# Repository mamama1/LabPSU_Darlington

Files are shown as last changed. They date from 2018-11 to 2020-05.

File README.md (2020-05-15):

# LabPSU_Darlington

Welcome to my Lab PSU project, which is based on a pair of BD139/TIP3055 Darlingtons and the Teensy 3.5 (3.6 should work as well).<br><br>

This project has been heavily inspired by the original µSupply project by Dave Jones from the EEVBlog.<br>
Link: https://www.eevblog.com/projects/usupply/ <br><br>

Specs:<br>
0 - 16.384V output controllable in 1mV steps<br>
0 - 4096 mA output controllable in 1mA steps<br>
Around 0.1% accuracy due to high accuracy components<br>
16 Bit DACs (DAC8311)<br>
High precision voltage reference for the DACs (REF5040)
16 Bit ADCs (ADS1115)<br>
Low Ripple, Low Noise<br>
25kHz PWM/temperature controlled Fan output for standard PWM capable FANs<br>
One Board solution (toroidal transformer not onboard)<br>
Optional Front Panel for Display, rotary encoder, button and LED mounting<br>
Fast UI thanks to Teensy's 120 MHz frequency<br>
Header for ESP8266, ESP32 or basically any other UART compatible device, including 3.3V and GND as well as two I/O pins (one PWM capable)

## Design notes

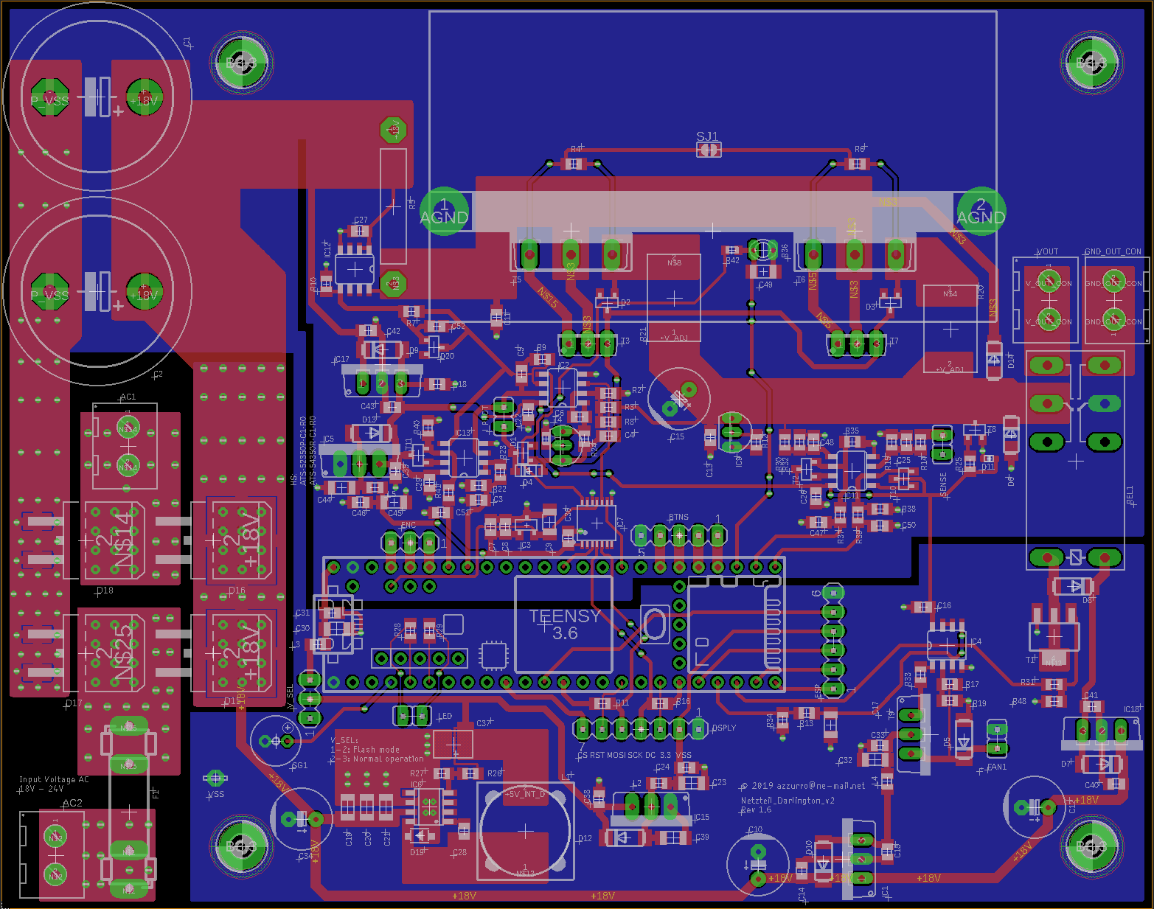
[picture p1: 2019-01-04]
Hardware/preview.PNG

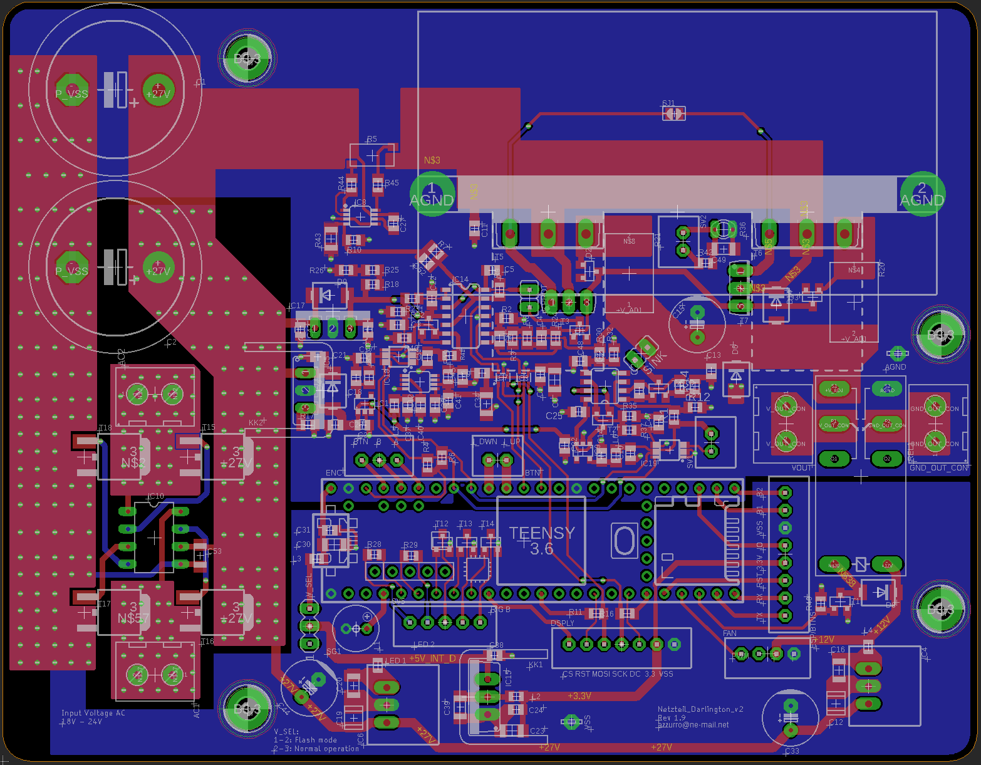
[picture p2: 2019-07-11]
preview.PNG

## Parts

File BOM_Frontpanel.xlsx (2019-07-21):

Qty | Value | Device | Package | Parts | Description | OC_MOUSER
1 |  | EC12E-SW | EC12E-SW | SW1 | ALPS ENCODER EC12-E with switch | 652-PEC11R-4225F-S24
1 |  | JST-PH-2.0-2P | JST-PH-2.0-2P | LED | PIN HEADER | 455-1704-ND
2 |  | JST-PH-2.0-3P | JST-PH-2.0-3P | ENC, RGB-LED | PIN HEADER | 455-1705-ND
1 |  | JST-PH-2.0-5P | JST-PH-2.0-5P | BTN | PIN HEADER | 455-1707-ND
1 |  | JST-PH-2.0-7P | JST-PH-2.0-7P | DSPLY | PIN HEADER | 455-1709-ND
1 |  | LED-RGB | C1411 | LED4 | LED | 710-150141M173100
4 |  | TS1B3F-10XX | B3F-10XX | TS1, TS2, TS3, TS4 |  | 653-B3F-1022
2 | 10k | R-SMD0805 | C0805K | R2, R3 | R | 652-CR0805-JW-103ELF
1 | 68R 1% 1/10W | R-SMD0805 | C0805K | R4 | R | 652-CR0805FX-68R0ELF
2 | 6R 1% 1/10W | R-SMD0805 | C0805K | R1, R5 | R | 652-CR0805-J/-6R2ELF
1 | DOC-R1.27 | DOC-R1.27 | DRAWINGNAME-1.27 | DNX-NAME-1 | devnetX Document Right
1 | G | LED0805 | LED0805 | LED1 | LED | 710-150080GS75000
6 | MOUNT-PAD-ROUND3.3 | MOUNT-PAD-ROUND3.3 | 3,3-PAD | H1, H2, H3, H4, H5, H6 | MOUNTING PAD, round
1 | NHD-2.7-12864WDW3 | NHD-2.7-12864WDW3 | NHD-2.7-12864WDW3 | DSPLY1 |  | 763-NHD2712864WDW3
1 | Y | LED0805 | LED0805 | LED2 | LED | 710-150080YS75000

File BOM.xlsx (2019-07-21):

Qty | Value | Device | Package | Parts | Description | OC_MOUSER | OC_MOUSER_ADD | OC_MOUSER_ADD2
2 |  | JP1E | JP1 | I_PROT, SINK | JUMPER
3 |  | JST-PH-2.0-2P | JST-PH-2.0-2P | BTN, NTC, NTC_ADC | PIN HEADER
1 |  | JST-PH-2.0-3P | JST-PH-2.0-3P | ENC | PIN HEADER
1 |  | JST-PH-2.0-4P | JST-PH-2.0-4P | FAN | PIN HEADER
1 |  | JST-PH-2.0-5P | JST-PH-2.0-5P | LED | PIN HEADER
1 |  | JST-PH-2.0-7P | JST-PH-2.0-7P | DSPLY | PIN HEADER
1 |  | JST-PH-2.0-8P | JST-PH-2.0-8P | ESP/BTNS | PIN HEADER
1 |  | KL2691311500002 | KL2-691311500002 | VOUT | Printklemme 2-polig | 710-691311500002 | 565-72912-2 | 565-6883
1 |  | MA03-1 | MA03-1 | V_SEL | PIN HEADER
2 | 0R1 0.5% 7W | R-SMDSLN2 | SLN2 | R20, R21 | R | 66-SLN5TTED82L0D
1 | 1.27R 1% 1/10W | R-SMD0805 | C0805K | R19 | R | 71-CRCW08051R27FKEA
2 | 10.1k 0.1% 10ppm 1/10W | R-SMD0805 | C0805K | R22, R32 | R | 660-RN732ATTD1012B25
2 | 10000µ/50V | CPOL-USE10-22.5 | EB22,5D | C1, C2 | POLARIZED CAPACITOR, American symbol | 647-UVZ1H103MRD
2 | 100R 0.1% 5ppm 1/10W | R-SMD0805 | C0805K | R44, R45 | R | 756-PCF080513100RBT1
1 | 100k | NTC640 | P640 | R36 | PHILIPS NTC | 594-NTCLE213E3104HXB
1 | 100n opt/50V | CC/0805 | 805 | C13 | Kondensator | 810-C2012X7R2A104K
9 | 100n/16V | CC/0805 | 805 | C3, C7, C9, C10, C17, C24, C31, C38, C48 | Kondensator | 810-C2012X7R2A104K
5 | 100n/35V | CC/0805 | 805 | C22, C25, C28, C40, C43 | Kondensator | 810-C2012X7R2A104K
1 | 100n/50V | CC/0805 | 805 | C27 | Kondensator | 810-C2012X7R2A104K
3 | 100µ/50V | C+3.5/8 | C+/3.5/8 | C15, C33, C44 |  | 667-EEU-FR1H101
1 | 10R 0.5% 50 ppm 1/4W | R-SMD0805 | C0805K | R14 | R | 660-SG73G2ATTD10R0D
1 | 10k 0.1% 10ppm | R-SMD0805 | C0805K | R2 | R | 667-ERA-6ARW103V
4 | 10k 5% 1/10W | R-SMD0805 | C0805K | R4, R6, R7, R48 | R | 652-CR0805-JW-103ELF
1 | 10m 0.1% 15ppm 0.5W | R-CSM2512 | CSM2512 | R5 |  | 71-CSM25120R0100BST
2 | 10n/16V | CC/0805 | 805 | C47, C51 | Kondensator | 80-C0805C103K1R
1 | 10n/50V | CC/0805 | 805 | C4 | Kondensator | 80-C0805C103K1R
7 | 10µ/16V | CC/1206 | 1206 | C8, C20, C23, C30, C34, C39, C49 | Kondensator | 963-TMK316AB7106KL-T
1 | 10µ/25V | CC/1206 | 1206 | C16 | Kondensator | 963-TMK316AB7106KL-T
2 | 10µ/50V | CAPACITOR-1210 | C1210 | C12, C19 | Capacitors | 81-GRM32ER71H106MA2L
1 | 12k 0.5% 50 ppm 1/10W | R-SMD0805 | C0805K | R1 | R | 754-RR1220P-123D
1 | 1k 0.5% 50 ppm 1/10W | R-SMD0805 | C0805K | R13 | R | 754-RR1220P-102D
4 | 1k 1% 1/8W | R-SMD0805 | C0805K | R18, R24, R25, R26 | R | 652-CR0805FX-1001ELF
1 | 1k5 5% 1/8W | R-SMD0805 | C0805K | R15 | R | 652-CR0805FX-1501ELF
2 | 1n/50V | CC/0805 | 805 | C5, C26 | Kondensator | 603-CC805KRX7R0BB102
5 | 1µ/16V | CC/0805 | 805 | C14, C18, C36, C41, C45 | Kondensator | 963-UMK212B7105KG-T
3 | 1µ/35V | CC/0805 | 805 | C32, C35, C37 | Kondensator | 963-UMK212B7105KG-T
1 | 1µ/50V | CC/1206 | 1206 | C53 | Kondensator | 603-CC126KKX7R9BB105
2 | 2.2k 5% 1/10W | R-SMD0805 | C0805K | R37, R41 | R | 652-CR0805FX-2201ELF
2 | 220R 5% 1/10W | R-SMD0805 | C0805K | R28, R29 | R | 652-CR0805FX-2200ELF
1 | 221R 0.5% 50ppm 1/10W | R-SMD0805 | C0805K | R12 | R | 754-RR1220P-2210D-M
2 | 22R 5% 1/10W | R-SMD0805 | C0805K | R11, R16 | R | 652-CR0805JW-220ELF
1 | 22p opt/35V C0G | CC/0805 | 805 | C52 | Kondensator | 603-CC805JRNPO9BN220
1 | 22pF/35V C0G | CC/0805 | 805 | C6 | Kondensator | 603-CC805JRNPO9BN220
1 | 2k2 5% 1/8W | R-SMD0805 | C0805K | R17 | R | 652-CR0805JW-222ELF
1 | 30k 0.1% 10ppm | R-SMD0805 | C0805K | R3 | R | 667-ERA-6ARW303V
1 | 330n opt/50V | CC/0805 | 805 | C11 | Kondensator | 80-C0805C334K5RECTU
2 | 330n/50V | CC/0805 | 805 | C21, C42 | Kondensator | 80-C0805C334K5RECTU
1 | 4.7k 1% 1/10W | R-SMD0805 | C0805K | R9 | R | 652-CR0805FX-4701ELF
2 | 4.7k 5% 1/10W | R-SMD0805 | C0805K | R35, R40 | R | 652-CR0805FX-4701ELF
1 | 4.7k opt 1% 1/10W | R-SMD0805 | C0805K | R10 | R | 652-CR0805FX-4701ELF
1 | 47k 1% 1/10W | R-SMD0805 | C0805K | R8 | R | 652-CR0805FX-4702ELF
1 | 5k 0.1% 25ppm | R-EU_R1206 | R1206 | R43 | RESISTOR, European symbol | 71-TNPW12065K00BEEN
1 | 64.9k 1% 1/10W | R-SMD0805 | C0805K | R42 | R | 652-CR0805FX-6492ELF
1 | 7815TV | 7815TV | TO220V | IC5 | Positive VOLTAGE REGULATOR | 511-L7815CV-DG
1 | 7818TV | 7818TV | TO220V | IC17 | Positive VOLTAGE REGULATOR | 511-L7818CV-DG
2 | 90.9k 0.1% 10ppm 1/10W | R-SMD0805 | C0805K | R23, R30 | R | 279-RN73CA-90.9K
1 | AC1 | KL2691311500002 | KL2-691311500002 | AC1 | Printklemme 2-polig | 710-691311500002 | 693-8601.2001.08 | 693-3101.0010
1 | AC2 | KL2691311500002 | KL2-691311500002 | AC2 | Printklemme 2-polig | 710-691311500002 | 693-8601.2001.08
2 | ADS1115 | ADS1015 | MSOP10 | IC18, IC19 | ADS1015 12-BIT ADC | 595-ADS1115IDGSR
3 | BAT54FILMY | DBAT54FILMY | SOT23 | D1, D2, D3 |  | 511-BAT54FILMY
2 | BC847ALT1G | T-NPNSOT23-BEC | SOT23-BEC | T2, T11 | NPN Transistor | 863-BC847ALT1G
2 | BD139 | T-NPNTO126-ECB | TO126 | T3, T7 | NPN Transistor | 511-BD139-10
1 | BUZZER | BUZZER | 254-EMB73-RO | SG1 | BUZZER Source: Buerklin | 254-EMB73-RO
5 | CGRB307-G | DWIDE | DO214AA-CGRB307-G | D4, D6, D8, D9, D14 |  | 750-CGRB307-G
1 | D01S | D01S | D01S | KK1 | HEATSINK
2 | DAC8311 | DAC8X11 | SC-70-6 | IC3, IC7 |  | 595-DAC8311IDCKR
1 | G2R-2-DC12 | REL-2UG2R2 | REL-G2R2 | REL1 |  | 653-G2R-2-DC12
1 | GND | KL2691311500002 | KL2-691311500002 | GND_OUT_CON | Printklemme 2-polig | 710-691311500002
1 | HSOMNI-UNI-41-75 | HSOMNI-UNI-41-75 | OMNI-UNI-41-75 | HS2 |  | 567-OMNI-UNI-41-75 | 567-OMNI-UC | 567-CD-02-05-247
4 | IRFR7546TRPBF | T-NMOSNTD4963N | DPACK | T15, T16, T17, T18 | Transistor N-Channel MOSFET | 942-IRFR7546TRPBF
1 | LD33V | LD33V | TO220V | IC15 |  | 511-LD1117V33
2 | LSP13 | LSP13 | LSP13 | AGND, VSS | SOLDER PAD drill 1.3 mm, distributor Buerklin, 12H562
1 | LT4320DIL08 | LT4320DIL08 | DIL08 | IC10 |  | 584-LT4320HN8-1#PBF
1 | LTC6102HMS8#PBF | LTC6102 | MSOP8-0.65-3X3MM | IC8 |  | 584-LTC6102HMS8#PBF
4 | MOUNT-PAD-ROUND3.3 | MOUNT-PAD-ROUND3.3 | 3,3-PAD | H1, H2, H3, H4 | MOUNTING PAD, round
7 | MPZ2012S601AT000 | L0805 | C0805K | L1, L2, L3, L4, L5, L6, L8 | High Power Density, High Efficiency, Shielded Inductors | 810-MPZ2012S601AT000
2 | NCP718BSN330T1G | NCP718 | SOT23-5 | IC1, IC9 |  | 863-NCP718BSN330T1G
1 | OPA2197 | DUAL-OPVSOP8 | SOP8 | IC2 |  | 595-OPA2197IDR
5 | PMV130ENEAR | T-NMOSIRLML2502PBF | SOT23 | T1, T4, T12, T13, T14 | Transistor N-Channel MOSFET | 771-PMV130ENEAR
1 | QUAD-OPVOPA4197 | QUAD-OPVOPA4197 | SO14 | IC14 |  | 595-OPA4197IDR
1 | REF5040 | REF50XXVSSOP8 | MSOP8-0.65-3X3MM | IC12 |  | 595-REF5040AIDGKR
1 | TEENSY_3.5/3.6 | TEENSY_3.5/3.6 | TEENSY_3.5/3.6 | U$33 |  | 474-DEV-14055
2 | TIP3055 | T-NPNTOP3AV-BCE | TOP3AV | T5, T6 | NPN Transistor | 863-TIP3055G
1 | VXO78012-1000 | 78XX-DC-DC-UNI-VXO-OKI | 78XX-DC-DC | IC4 |  | 490-VXO7812-1000
1 | VXO7805-1000 | 78XX-DC-DC-UNI-VXO-OKI | 78XX-DC-DC | IC6 |  | 490-VXO7805-1000

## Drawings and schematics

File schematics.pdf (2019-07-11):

# REF3120AIDBZR or REF5020AIDR as VREF Y08500R01000F9R shunt

# AGND¹⁰⁰R ⁰.1% ⁵ppm ¹/10W

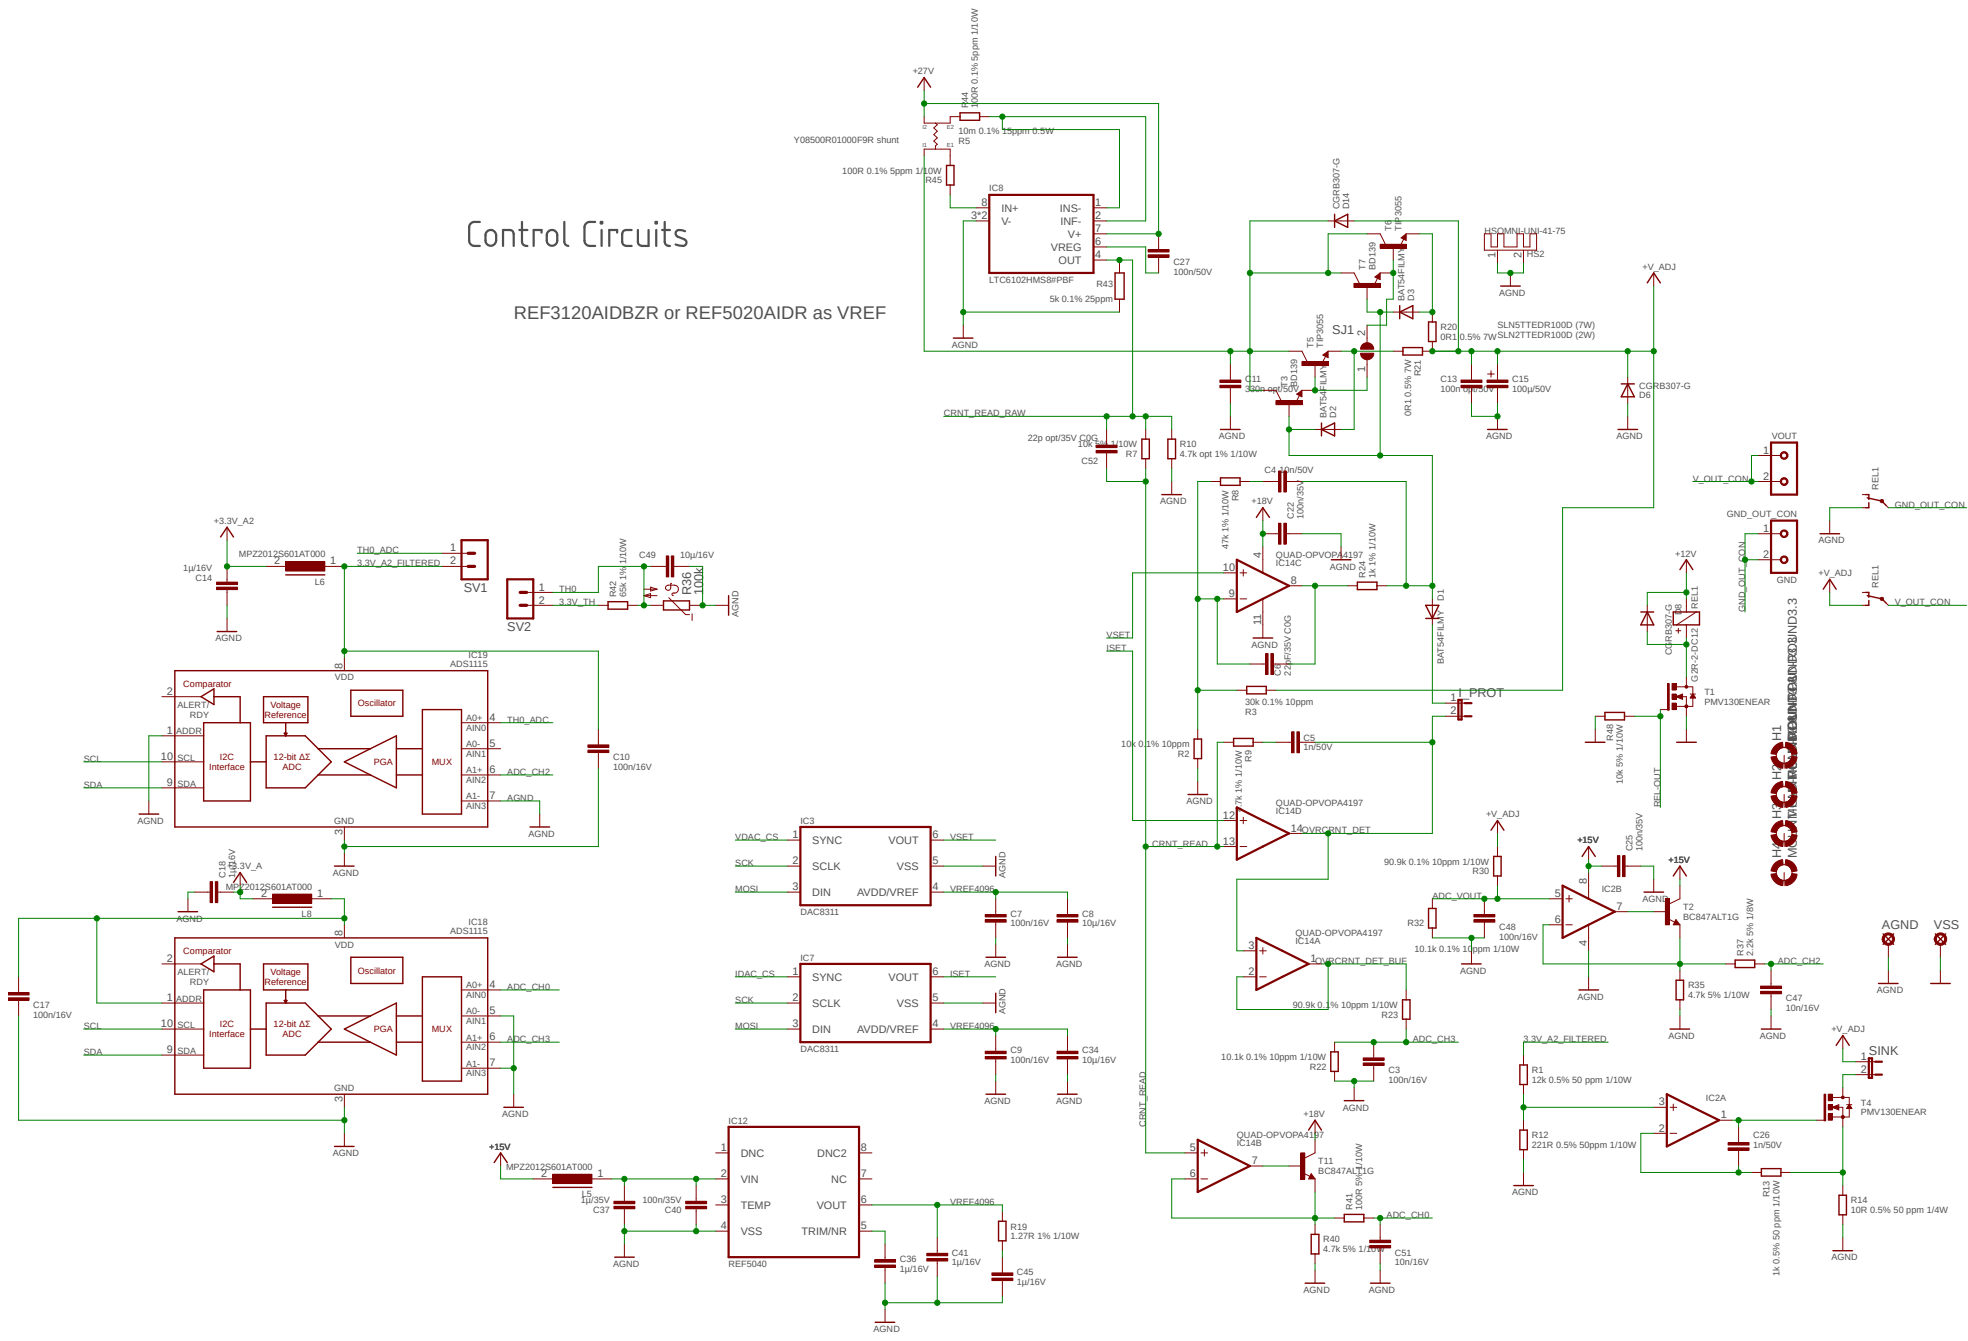
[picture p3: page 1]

## 6mA Pulldown AC¹

LT4320DIL08 IRFR⁷⁵⁴⁶TRPBF | IRFR⁷⁵⁴⁶TRPBF IRFR⁷⁵⁴⁶TRPBF | IRFR⁷⁵⁴⁶TRPBF

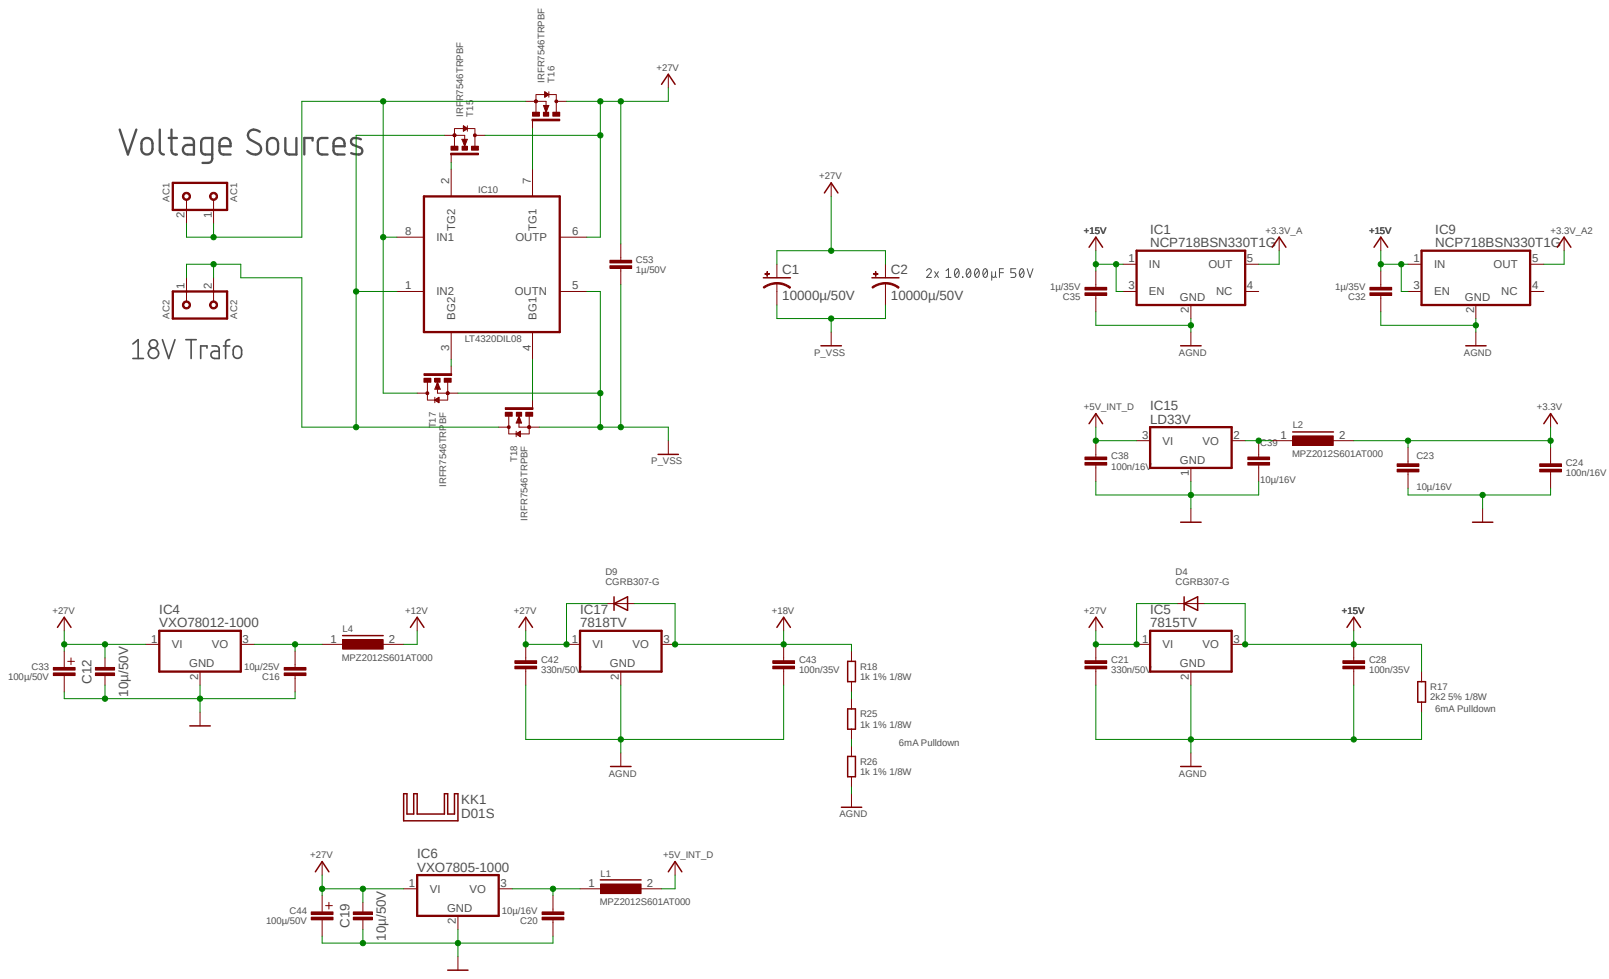
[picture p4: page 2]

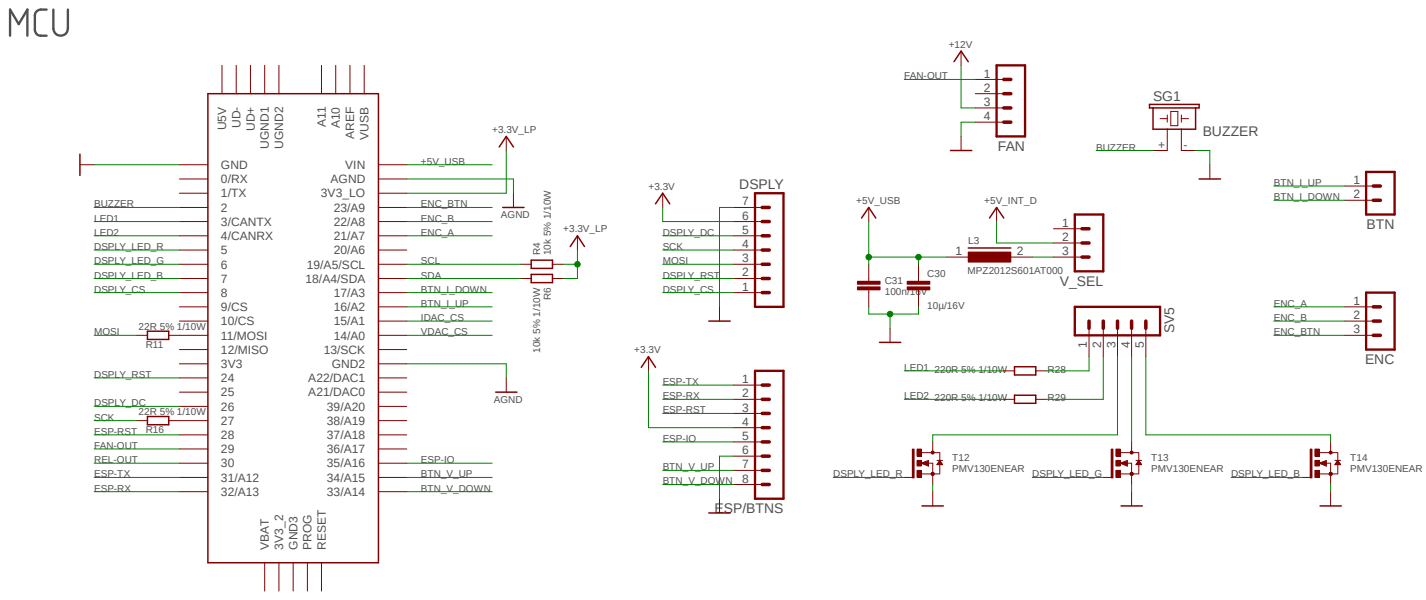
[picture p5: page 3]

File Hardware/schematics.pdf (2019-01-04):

REF3120AIDBZR or REF5020AIDR as VREF | R

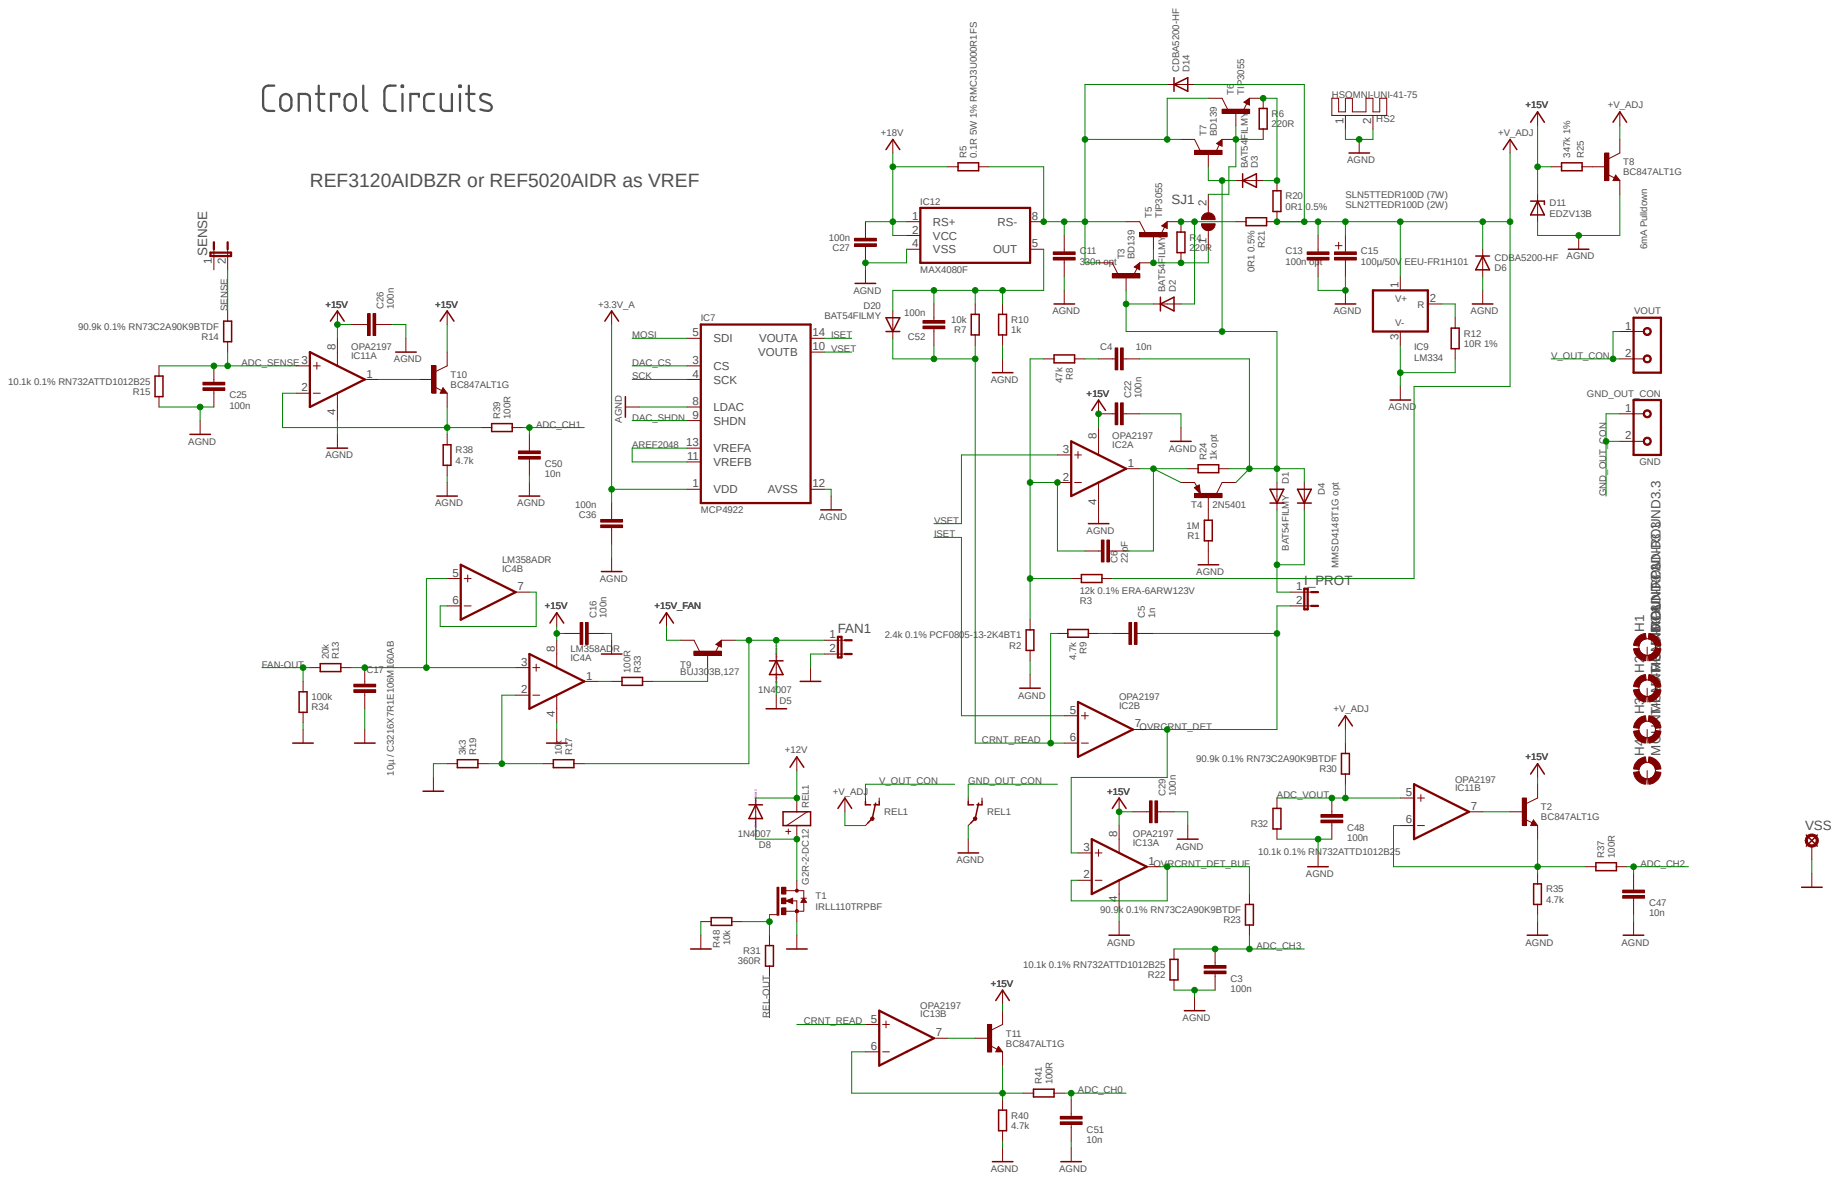
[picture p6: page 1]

SpiceOrder 1 SpiceOrder 2 SpiceOrder 1 SpiceOrder 2 6mA PulldownSLN5TTEDR100D (7W)

### 6mA Pulldown AC¹

# UVZ1H103MRD UVZ1H103MRD

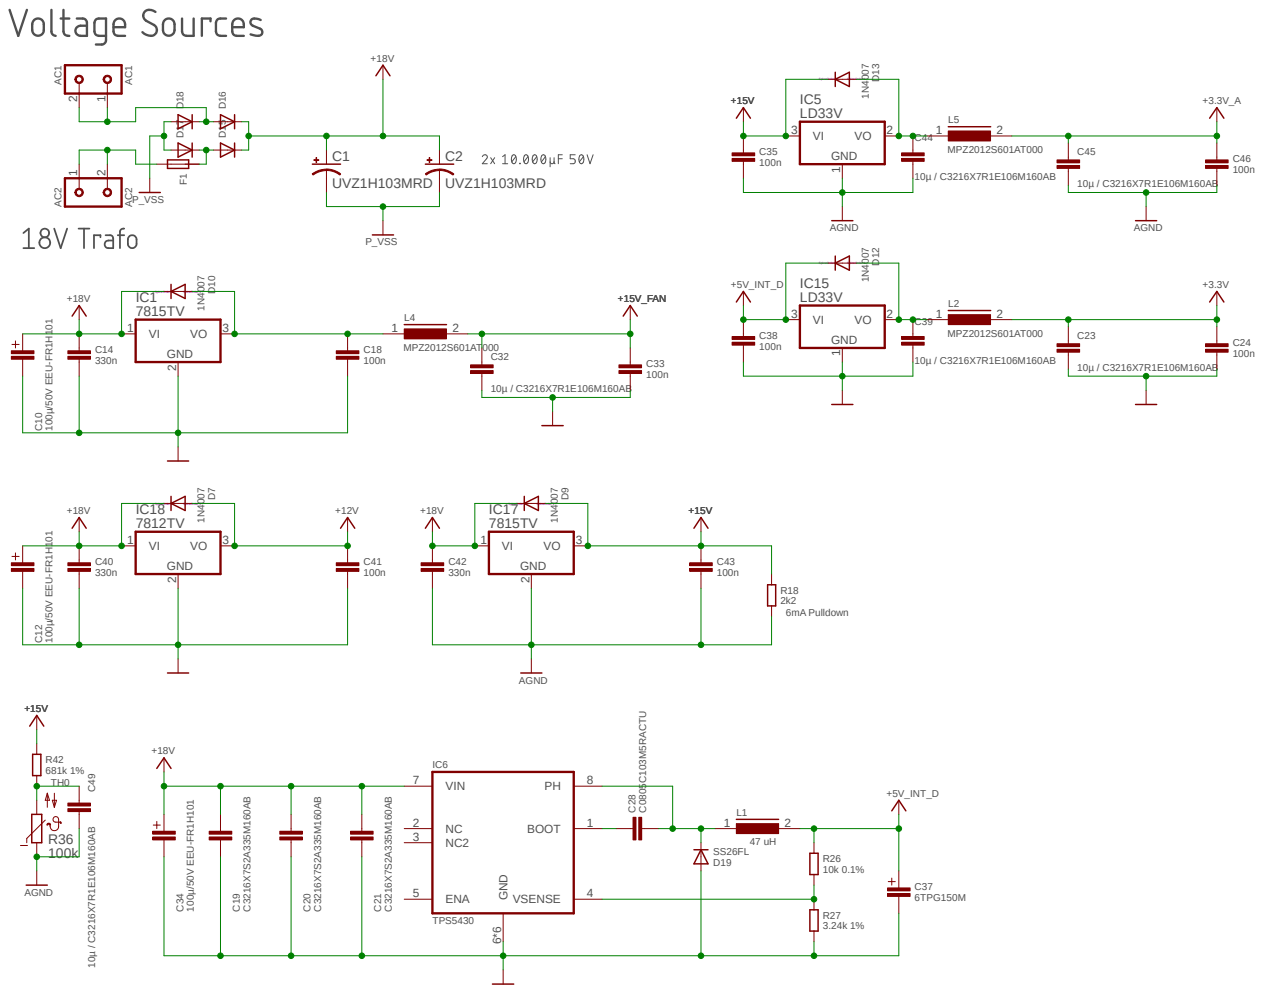
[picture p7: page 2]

P_VSS 100µ/50V EEU⁻FR¹H¹⁰¹ 100µ/50V EEU⁻FR¹H¹⁰¹

### IN OUT

### +3.3V_A

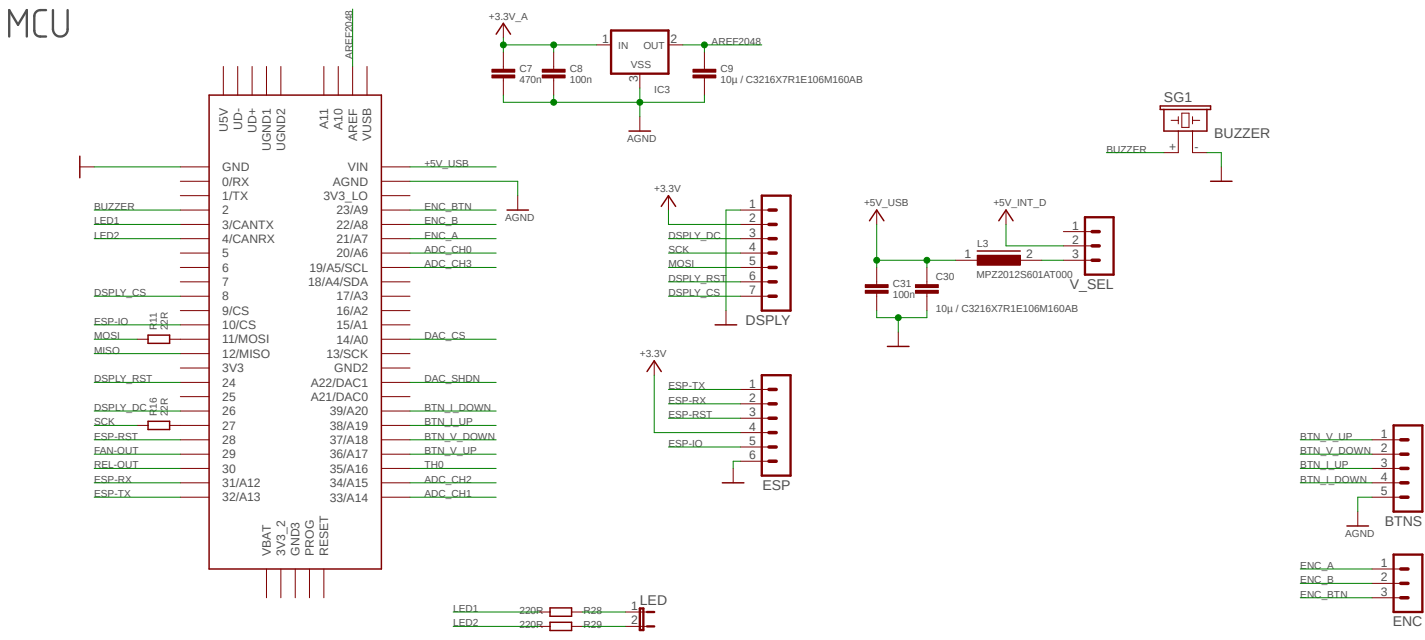
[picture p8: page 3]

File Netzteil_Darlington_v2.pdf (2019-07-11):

+

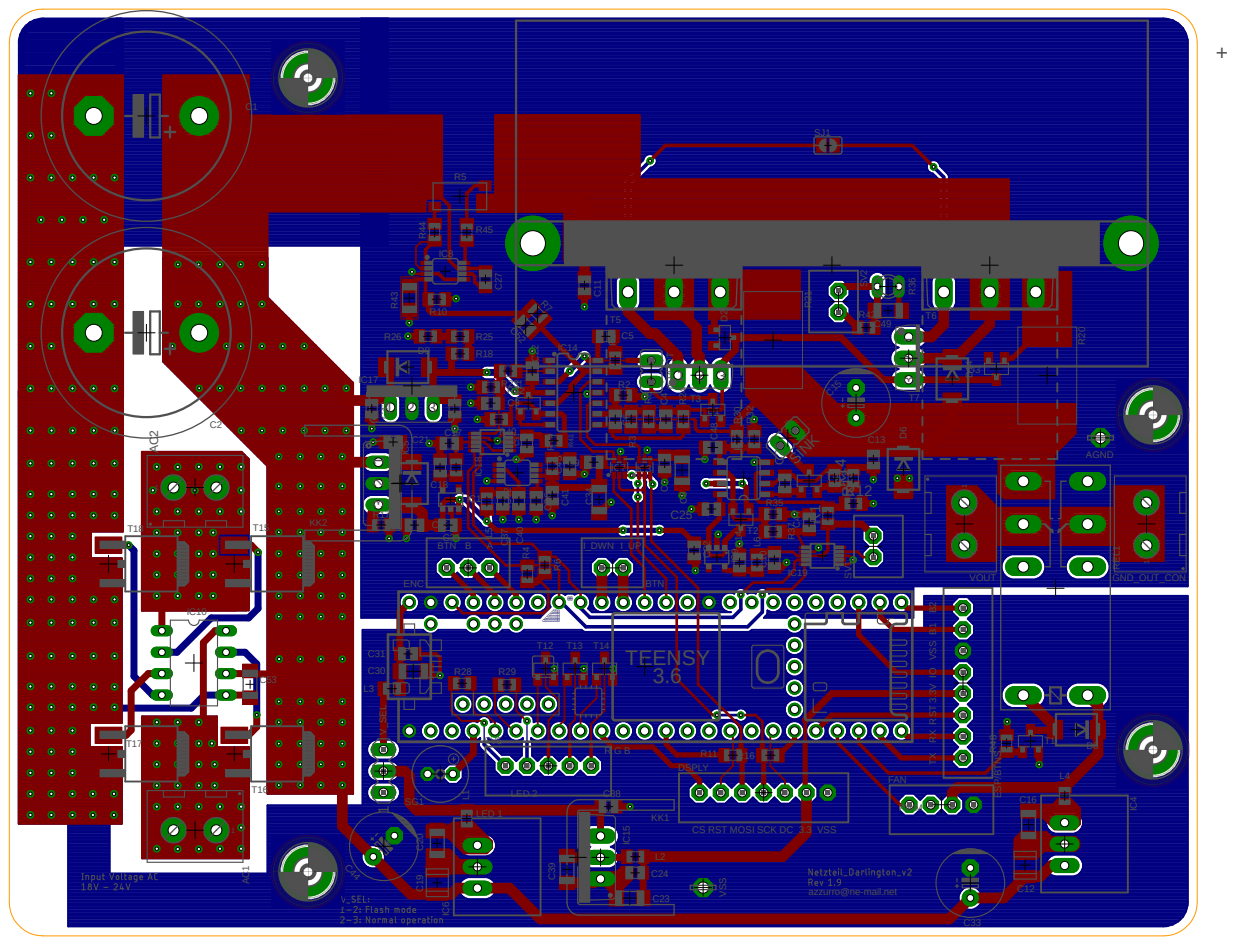
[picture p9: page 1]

+ CS RST MOSI SCK DC 3.3 VSS

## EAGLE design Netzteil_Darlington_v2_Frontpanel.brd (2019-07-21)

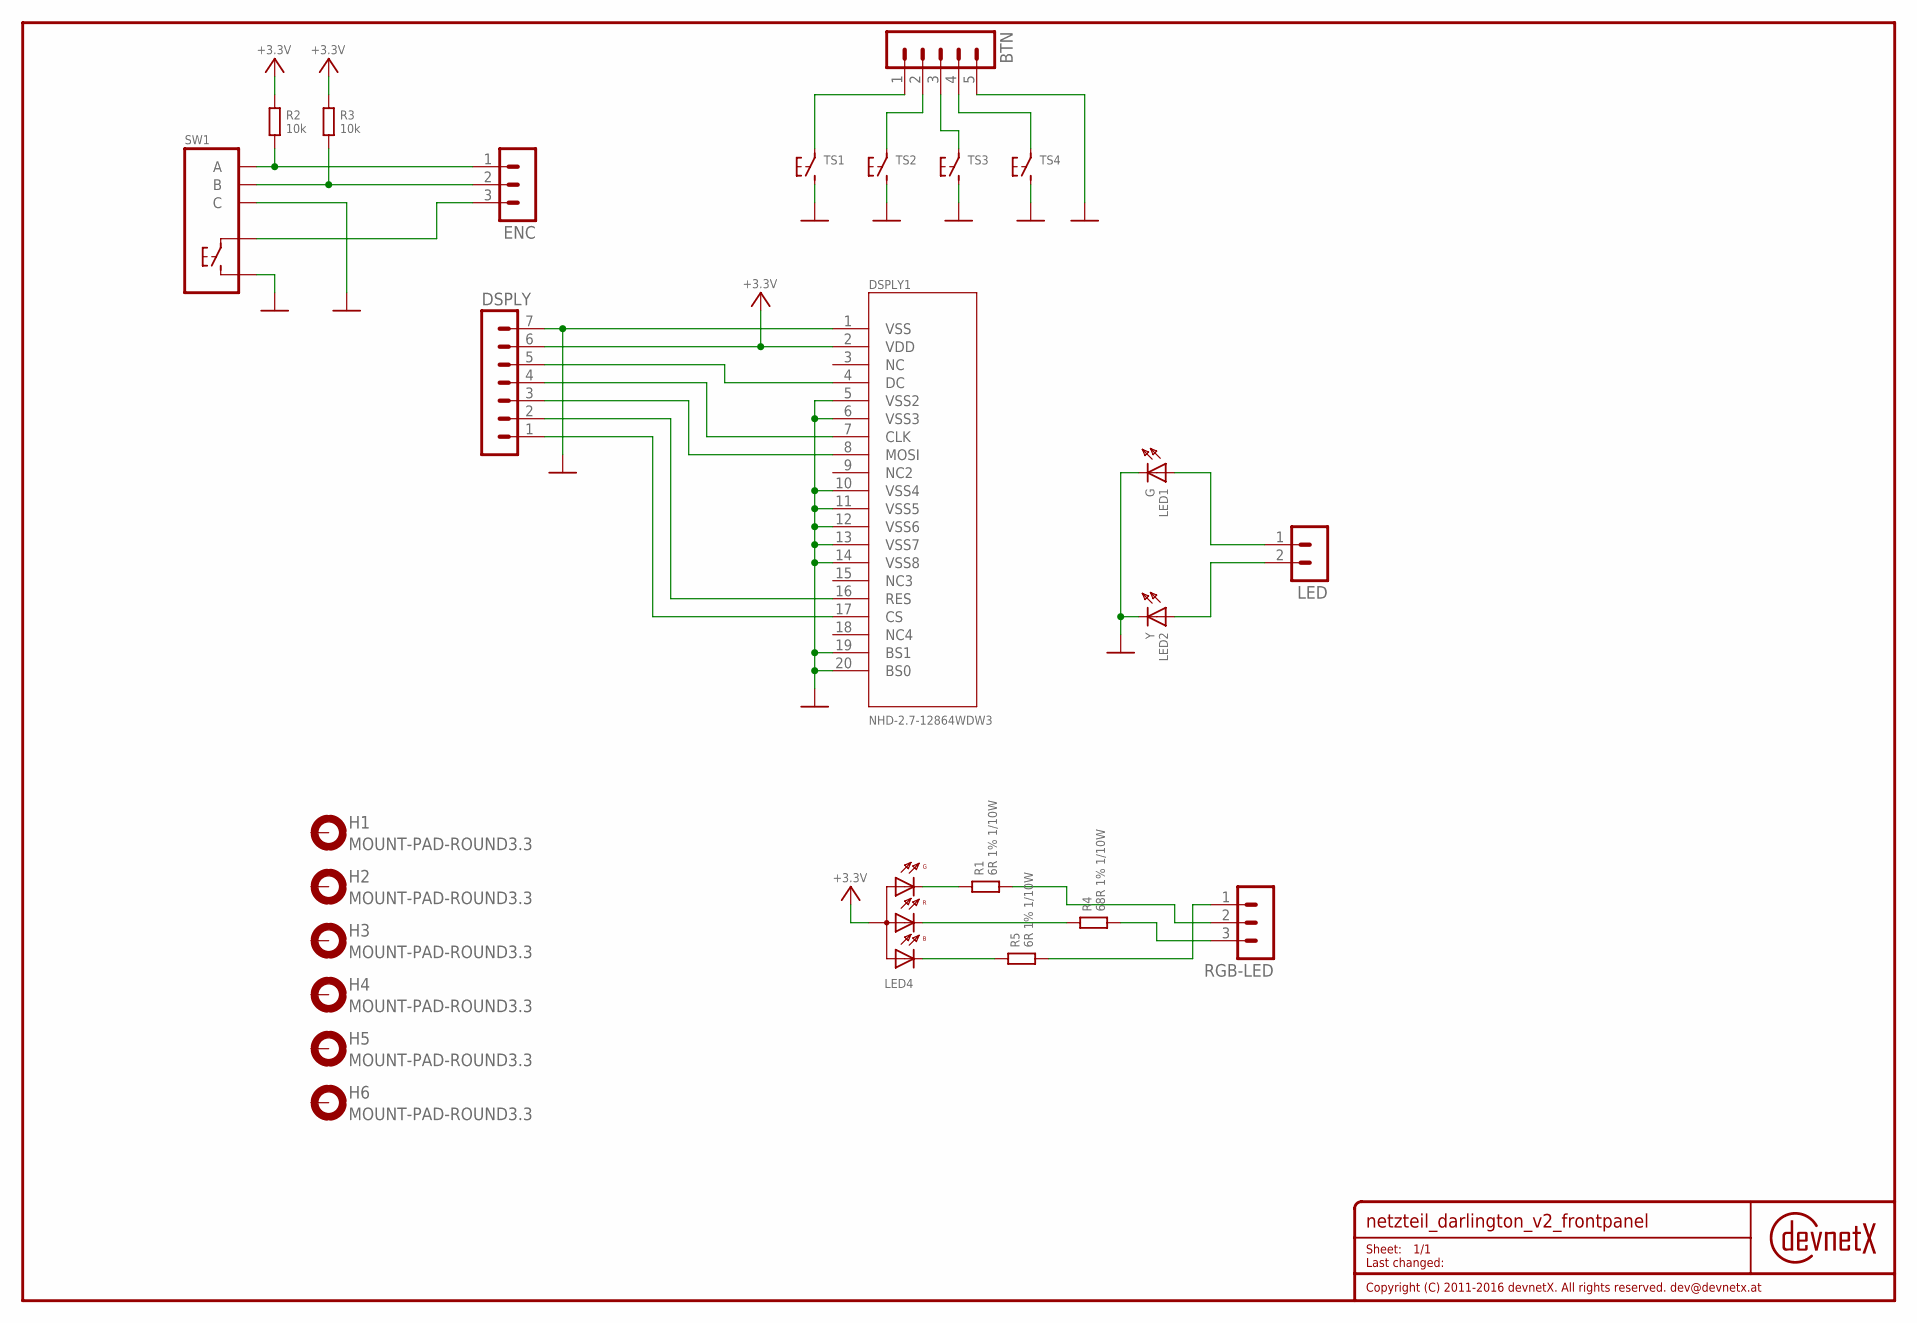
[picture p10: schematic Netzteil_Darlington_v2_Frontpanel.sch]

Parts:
BTN: JST-PH-2.0-5P
DNX-NAME-1: DOC-R1.27; DRAWINGNAME-1.27
DSPLY: JST-PH-2.0-7P
DSPLY1: NHD-2.7-12864WDW3
ENC: JST-PH-2.0-3P
H1, H2, H3, H4, H5, H6: MOUNT-PAD-ROUND3.3; 3,3-PAD
LED: JST-PH-2.0-2P
LED1: G; LED0805
LED2: Y; LED0805
LED4: LED-RGB; C1411
R1, R5: 6R 1% 1/10W; C0805K
R2, R3: 10k; C0805K
R4: 68R 1% 1/10W; C0805K
RGB-LED: JST-PH-2.0-3P
SW1: EC12E-SW
TS1, TS2, TS3, TS4: TS1B3F-10XX; B3F-10XX

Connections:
+3.3V: DSPLY.6, DSPLY1.2 (VDD), LED4.1 (A), R2.1, R3.1
unnamed: LED.1, LED1.A
unnamed: LED.2, LED2.A
unnamed: DSPLY.5, DSPLY1.4 (DC)
unnamed: BTN.1, TS1.1
unnamed: ENC.1, R2.2, SW1.A
unnamed: DSPLY.4, DSPLY1.7 (CLK)
unnamed: DSPLY.3, DSPLY1.8 (MOSI)
unnamed: LED4.4 (C4), R1.1
unnamed: ENC.2, R3.2, SW1.B
unnamed: ENC.3, SW1.1
unnamed: BTN.2, TS2.1
unnamed: BTN.3, TS3.1
unnamed: BTN.4, TS4.1
unnamed: LED4.3 (C3), R4.1
unnamed: DSPLY.2, DSPLY1.16 (RES)
unnamed: DSPLY.1, DSPLY1.17 (CS)
unnamed: LED4.2 (C2), R5.1
unnamed: R5.2, RGB-LED.1
unnamed: R4.2, RGB-LED.3
unnamed: R1.2, RGB-LED.2
VSS: BTN.5, DSPLY.7, DSPLY1.1 (VSS), DSPLY1.5 (VSS2), DSPLY1.6 (VSS3), DSPLY1.10 (VSS4), DSPLY1.11 (VSS5), DSPLY1.12 (VSS6), DSPLY1.13 (VSS7), DSPLY1.14 (VSS8), DSPLY1.19 (BS1), DSPLY1.20 (BS0), LED1.C, LED2.C, SW1.2, SW1.C, TS1.3 (2), TS2.3 (2), TS3.3 (2), TS4.3 (2)

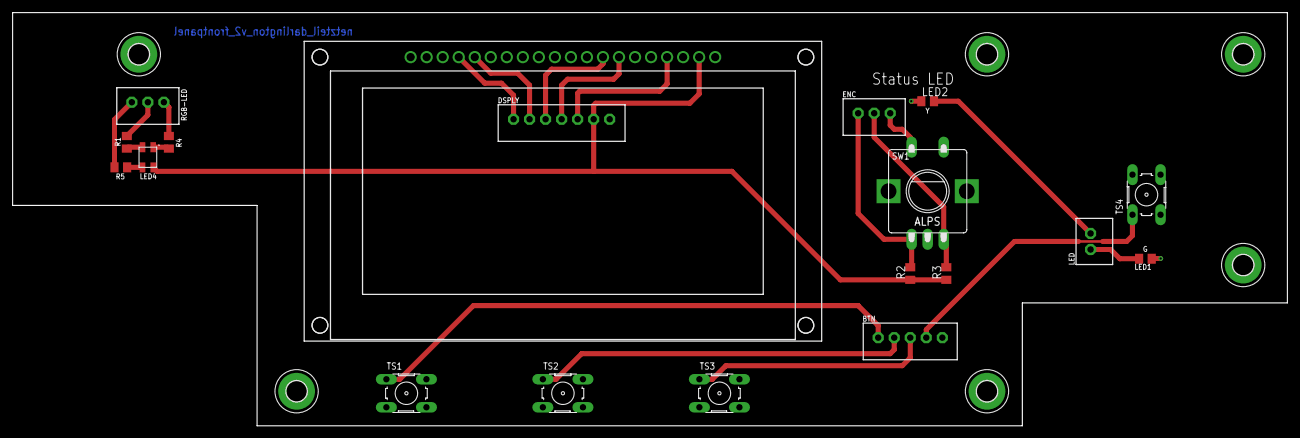
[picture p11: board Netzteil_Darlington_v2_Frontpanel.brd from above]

Board: 2 copper layers, 202.0 x 65.5 mm, 26 parts (0 on the bottom side), 22 nets.

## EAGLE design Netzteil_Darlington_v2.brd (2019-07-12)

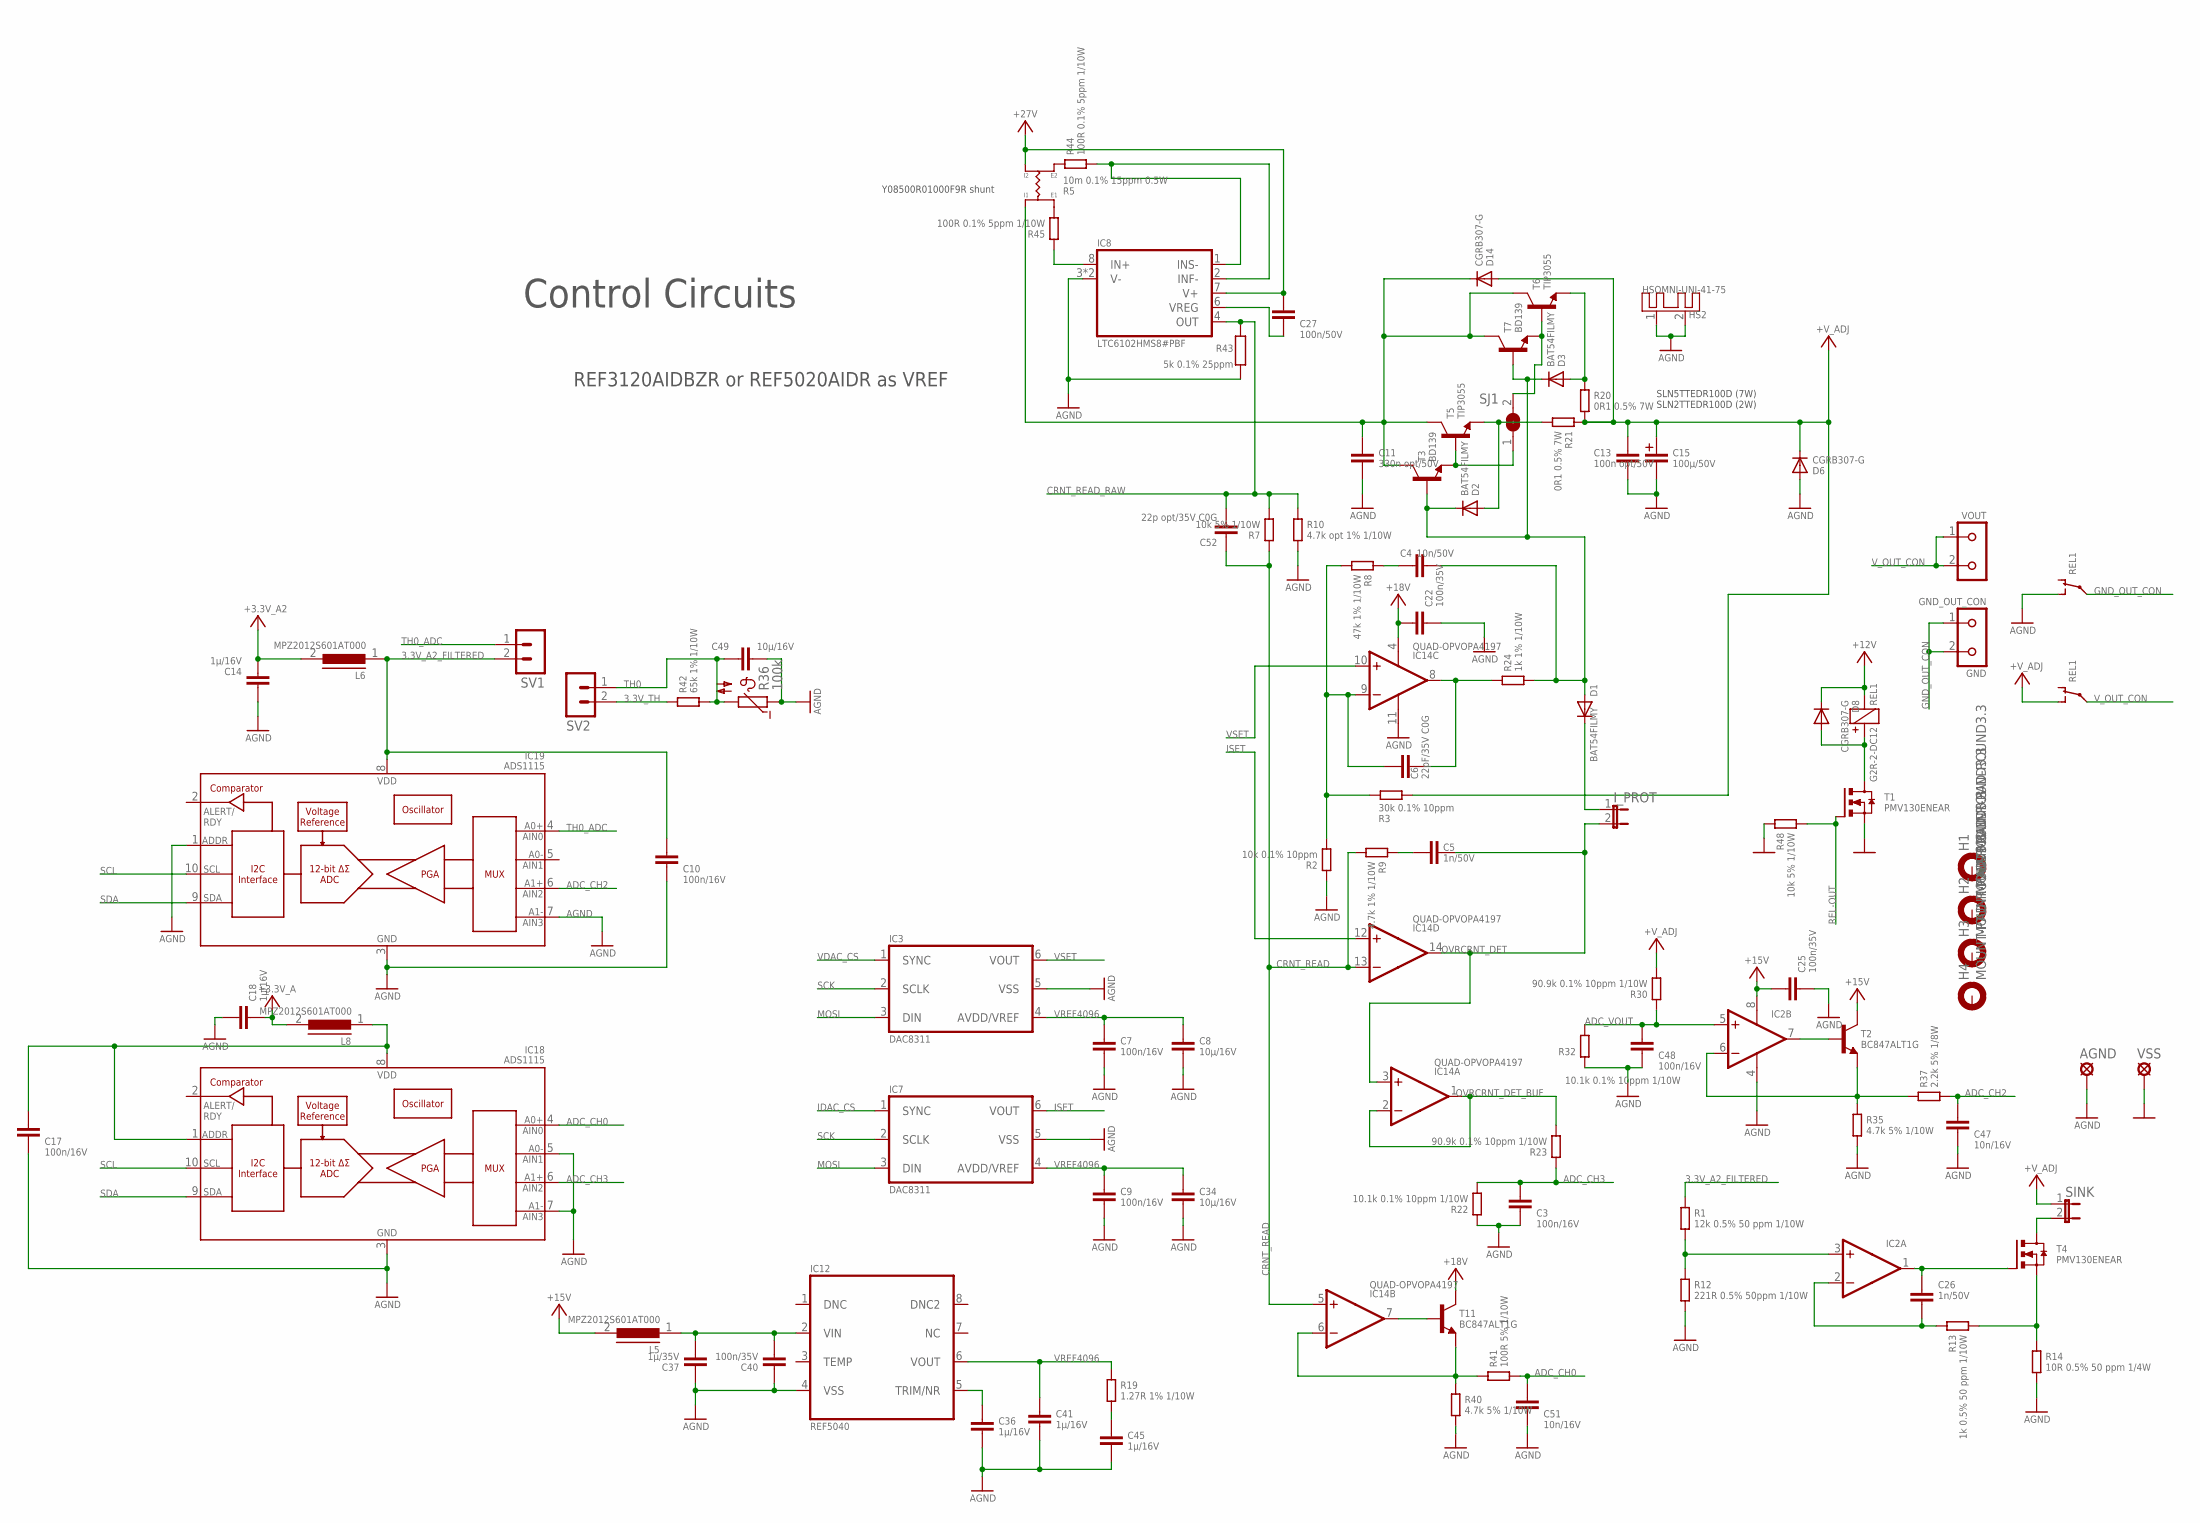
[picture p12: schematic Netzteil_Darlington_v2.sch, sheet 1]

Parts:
AGND: LSP13
C3, C7, C9, C10, C17, C48: 100n/16V; 0805
C4: 10n/50V; 0805
C5, C26: 1n/50V; 0805
C6: 22pF/35V C0G; 0805
C8, C34, C49: 10µ/16V; 1206
C11: 330n opt/50V; 0805
C13: 100n opt/50V; 0805
C14, C18, C36, C41, C45: 1µ/16V; 0805
C15: 100µ/50V; C+/3.5/8
C22, C25, C40: 100n/35V; 0805
C27: 100n/50V; 0805
C37: 1µ/35V; 0805
C47, C51: 10n/16V; 0805
C52: 22p opt/35V C0G; 0805
D1, D2, D3: BAT54FILMY; SOT23
D6, D8, D14: CGRB307-G; DO214AA-CGRB307-G
GND_OUT_CON: GND; KL2-691311500002
H1, H2, H3, H4: MOUNT-PAD-ROUND3.3; 3,3-PAD
HS2: HSOMNI-UNI-41-75; OMNI-UNI-41-75
IC2: DUAL-OPVSOP8; SOP8
IC3, IC7: DAC8311; SC-70-6
IC8: LTC6102HMS8#PBF; MSOP8-0.65-3X3MM
IC12: REF5040; MSOP8-0.65-3X3MM
IC14: QUAD-OPVOPA4197; SO14
IC18, IC19: ADS1115; MSOP10
I_PROT: JP1E; JP1
L5, L6, L8: MPZ2012S601AT000; C0805K
R1: 12k 0.5% 50 ppm 1/10W; C0805K
R2: 10k 0.1% 10ppm; C0805K
R3: 30k 0.1% 10ppm; C0805K
R5: 10m 0.1% 15ppm 0.5W; CSM2512
R7, R48: 10k 5% 1/10W; C0805K
R8: 47k 1% 1/10W; C0805K
R9: 4.7k 1% 1/10W; C0805K
R10: 4.7k opt 1% 1/10W; C0805K
R12: 221R 0.5% 50ppm 1/10W; C0805K
R13: 1k 0.5% 50 ppm 1/10W; C0805K
R14: 10R 0.5% 50 ppm 1/4W; C0805K
R19: 1.27R 1% 1/10W; C0805K
R20, R21: 0R1 0.5% 7W; SLN2
R22, R32: 10.1k 0.1% 10ppm 1/10W; C0805K
R23, R30: 90.9k 0.1% 10ppm 1/10W; C0805K
R24: 1k 1% 1/10W; C0805K
R35, R40: 4.7k 5% 1/10W; C0805K
R36: 100k; P640
R37: 2.2k 5% 1/8W; C0805K
R41: 100R 5% 1/10W; C0805K
R42: 65k 1% 1/10W; C0805K
R43: 5k 0.1% 25ppm; R1206
R44, R45: 100R 0.1% 5ppm 1/10W; C0805K
REL1: G2R-2-DC12; REL-G2R2
SINK: JP1E; JP1
SJ1: SJ
SV1, SV2: JST-PH-2.0-2P
T1, T4: PMV130ENEAR; SOT23
T2, T11: BC847ALT1G; SOT23-BEC
T3, T7: BD139; TO126
T5, T6: TIP3055; TOP3AV
VOUT: KL2691311500002; KL2-691311500002
VSS: LSP13

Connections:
3.3V_TH: R42.1, SV2.2; also elsewhere on the board
+3.3V_A: C18.2, L8.2; also elsewhere on the board
+3.3V_A2: C14.2, L6.2; also elsewhere on the board
+12V: D8.C, REL1.-; also elsewhere on the board
+18V: C22.1, IC14.4 (V+), T11.C; also elsewhere on the board
+27V: C27.1, IC8.7 (V+), R5.I2; also elsewhere on the board
+V_ADJ: C13.1, C15.+, D6.C, D14.A, R3.1, R20.2, R21.1, R30.2, REL1.S1 (S), SINK.1
ADC_CH0: C51.1, IC18.4 (AIN0), R41.2
ADC_CH2: C47.1, IC19.6 (AIN2), R37.2
ADC_CH3: C3.1, IC18.6 (AIN2), R22.2, R23.1
ADC_VOUT: C48.1, IC2.5 (+IN), R30.1, R32.2
AGND: AGND.MP, C3.2, C7.2, C8.2, C9.2, C10.2, C11.2, C13.2, C14.1, C15.-, C17.2, C18.1, C22.2, C25.2, C34.2, C36.2, C37.1, C40.1, C41.2, C45.2, C47.2, C48.2, C49.1, C51.2, D6.A, HS2.1, HS2.2, IC2.4 (V-), IC3.5 (VSS), IC7.5 (VSS), IC8.3 (V-), IC8.5 (V-), IC12.4 (VSS), IC14.11 (V-), IC18.3 (VSS), IC18.5 (AIN1), IC18.7 (AIN3), IC19.1 (ADDR), IC19.3 (VSS), IC19.7 (AIN3), R2.1, R10.2, R12.2, R14.2, R22.1, R32.1, R35.2, R36.1, R40.2, R43.1, REL1.S2 (S); also elsewhere on the board
CRNT_READ: C52.1, IC14.5 (+IN), IC14.13 (-IN), R7.1, R9.2
CRNT_READ_RAW: C52.2, IC8.4 (OUT), R7.2, R10.1, R43.2
GND_OUT_CON: GND_OUT_CON.1, GND_OUT_CON.2, REL1.P2
IDAC_CS: IC7.1 (SYNC); also elsewhere on the board
ISET: IC7.6 (VOUT), IC14.12 (+IN)
MOSI: IC3.3 (DIN), IC7.3 (DIN); also elsewhere on the board
unnamed: C11.1, D14.C, R5.I1, T3.2 (C), T5.C, T6.C, T7.2 (C)
unnamed: D3.1 (A), R20.1, T6.E
unnamed: SJ1.2, T6.B, T7.1 (E)
unnamed: IC14.7 (OUT), T11.B
unnamed: D2.1 (A), R21.2, T5.E
unnamed: D1.3 (C), I_PROT.1
unnamed: IC2.3 (+IN), R1.2, R12.1
unnamed: C36.1, IC12.5 (TRIM/NR)
unnamed: SJ1.1, T3.1 (E), T5.B
unnamed: R13.2, R14.1, T4.2 (S)
unnamed: C26.2, IC2.2 (-IN), R13.1
unnamed: C6.2, IC14.8 (OUT), R24.1
unnamed: C4.2, D1.1 (A), D2.3 (C), D3.3 (C), R24.2, T3.3 (B), T7.3 (B)
unnamed: C17.1, IC18.1 (ADDR), IC18.8 (VDD), L8.1
unnamed: C37.2, C40.2, IC12.2 (VIN), L5.1
unnamed: C4.1, R8.1
unnamed: C5.1, R9.1
unnamed: C6.1, IC14.9 (-IN), R2.2, R3.2, R8.2
unnamed: C45.1, R19.2
unnamed: C26.1, IC2.1 (OUT), T4.1 (G)
unnamed: SINK.2, T4.3 (D)
unnamed: D8.A, REL1.+, T1.3 (D)
unnamed: IC2.6 (-IN), R35.1, R37.1, T2.E
unnamed: IC14.6 (-IN), R40.1, R41.1, T11.E
unnamed: IC8.8 (IN+), R45.1
unnamed: IC8.1 (INS-), IC8.2 (INF-), R44.2
unnamed: C27.2, IC8.6 (VREG)
unnamed: R5.E2, R44.1
unnamed: R5.E1, R45.2
OVRCRNT_DET: C5.2, IC14.3 (+IN), IC14.14 (OUT), I_PROT.2
OVRCRNT_DET_BUF: IC14.1 (OUT), IC14.2 (-IN), R23.2
REL-OUT: R48.2, T1.1 (G); also elsewhere on the board
SCK: IC3.2 (SCLK), IC7.2 (SCLK); also elsewhere on the board
SCL: IC18.10 (SCL), IC19.10 (SCL); also elsewhere on the board
SDA: IC18.9 (SDA), IC19.9 (SDA); also elsewhere on the board
TH0: C49.2, R36.2, R42.2, SV2.1; also elsewhere on the board
TH0_ADC: IC19.4 (AIN0), SV1.1; also elsewhere on the board
VDAC_CS: IC3.1 (SYNC); also elsewhere on the board
VREF4096: C7.1, C8.1, C9.1, C34.1, C41.1, IC3.4 (AVDD/VREF), IC7.4 (AVDD/VREF), IC12.6 (VOUT), R19.1
VSET: IC3.6 (VOUT), IC14.10 (+IN)
VSS: R48.1, T1.2 (S), VSS.MP; also elsewhere on the board
V_OUT_CON: REL1.P1, VOUT.1, VOUT.2

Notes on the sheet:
Control Circuits
SLN5TTEDR100D (7W) SLN2TTEDR100D (2W)
REF3120AIDBZR or REF5020AIDR as VREF
Y08500R01000F9R shunt

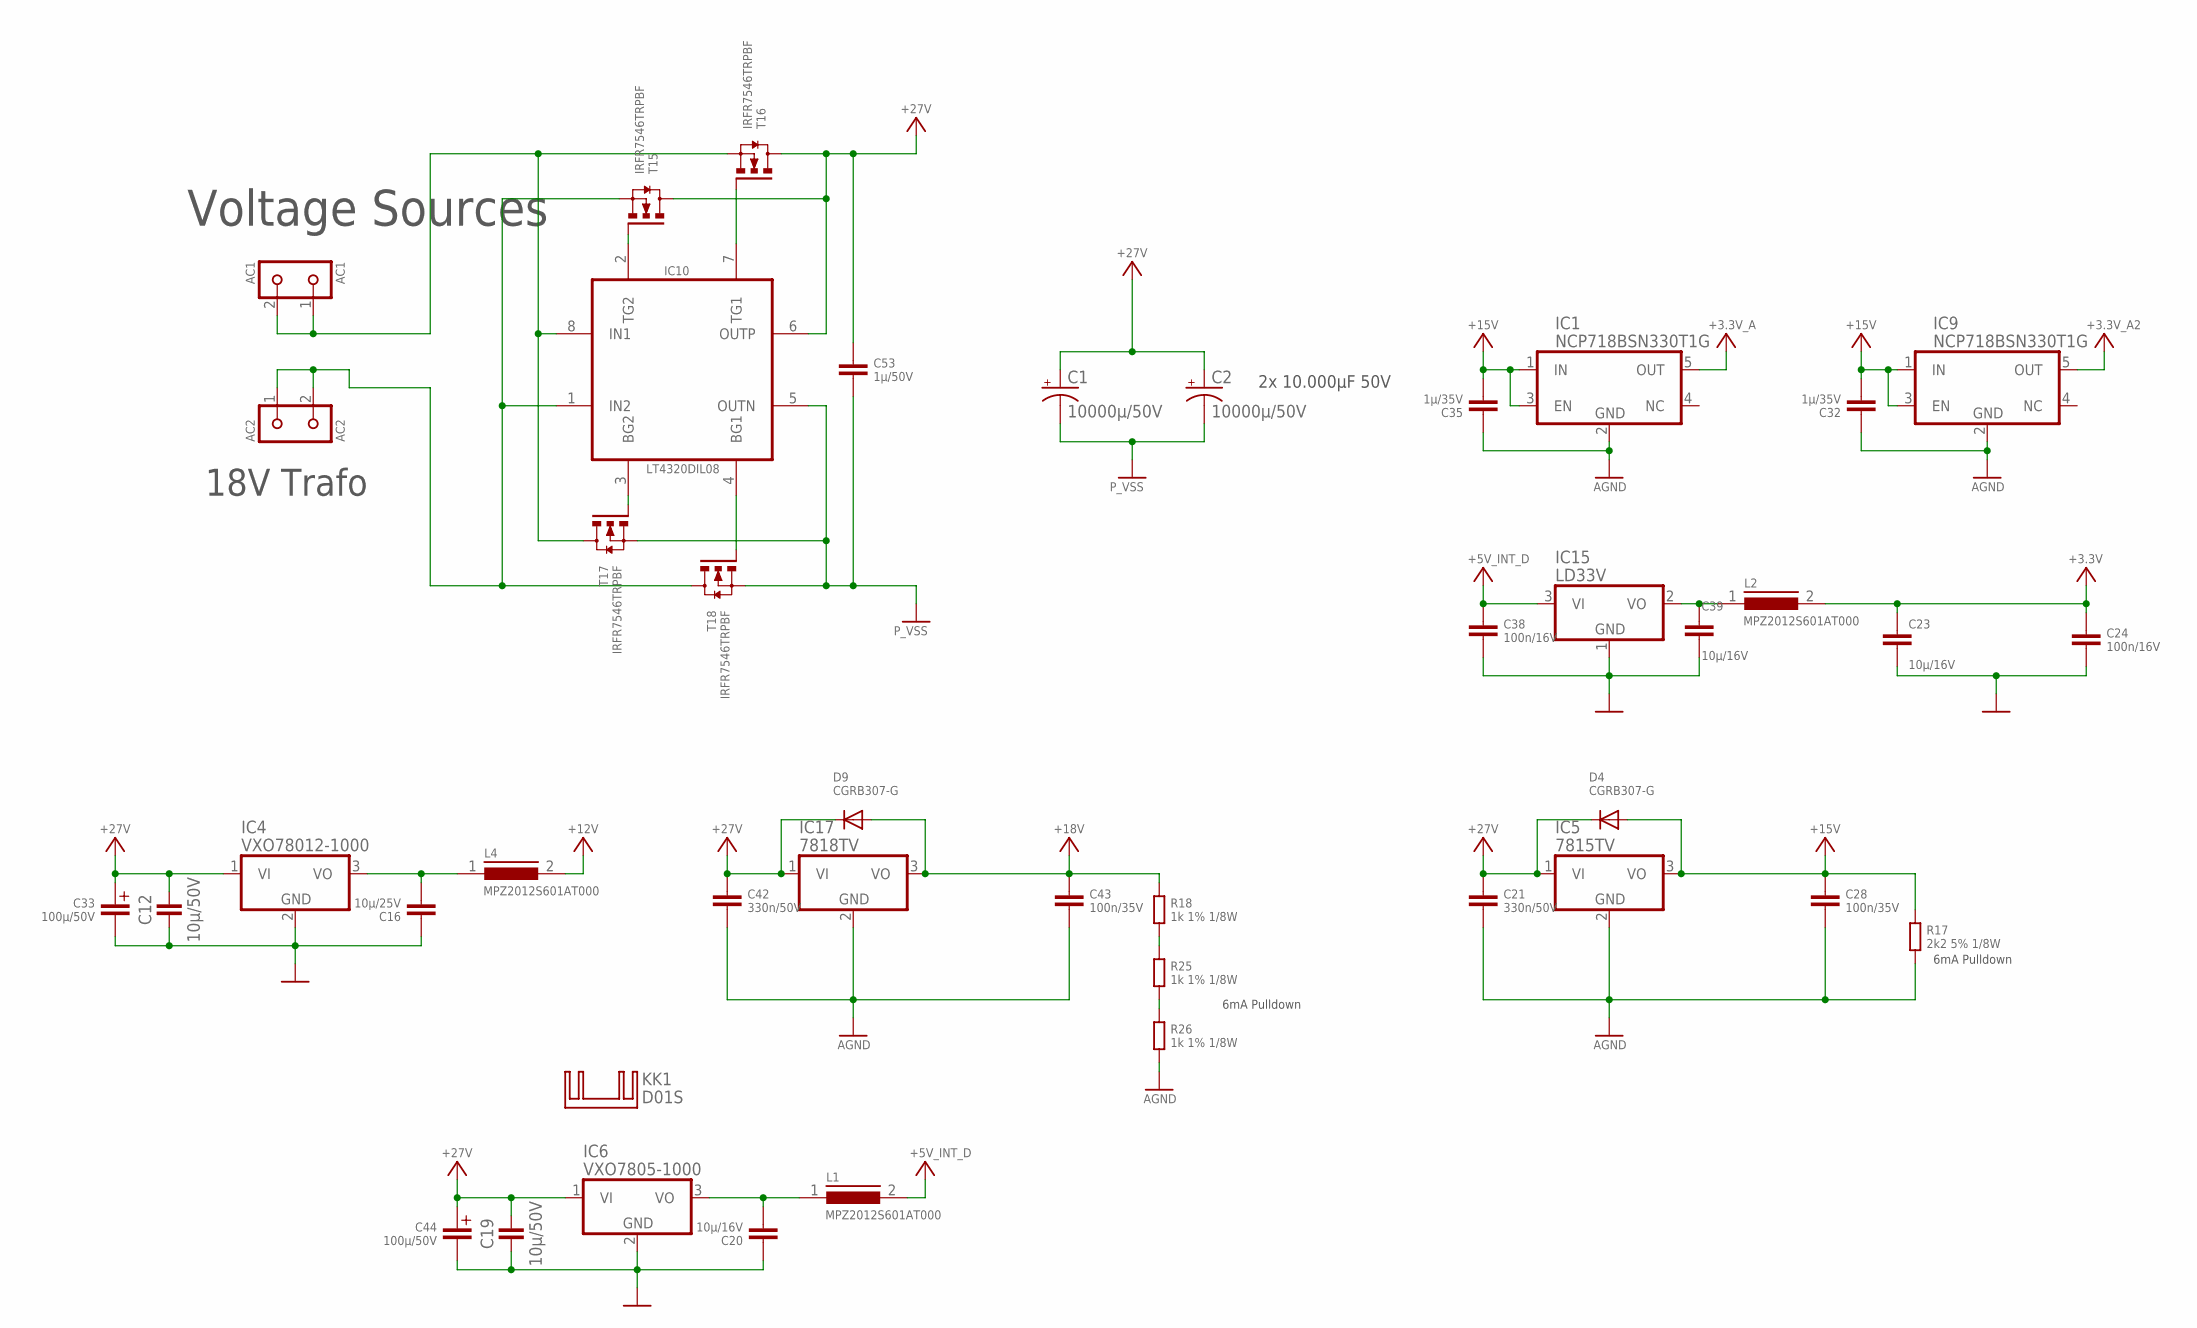
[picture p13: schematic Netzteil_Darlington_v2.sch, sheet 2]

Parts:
AC1: AC1; KL2-691311500002
AC2: AC2; KL2-691311500002
C1, C2: 10000µ/50V; EB22,5D
C12, C19: 10µ/50V; C1210
C16: 10µ/25V; 1206
C20, C23, C39: 10µ/16V; 1206
C21, C42: 330n/50V; 0805
C24, C38: 100n/16V; 0805
C28, C43: 100n/35V; 0805
C32, C35: 1µ/35V; 0805
C33, C44: 100µ/50V; C+/3.5/8
C53: 1µ/50V; 1206
D4, D9: CGRB307-G; DO214AA-CGRB307-G
IC1, IC9: NCP718BSN330T1G; SOT23-5
IC4: VXO78012-1000; 78XX-DC-DC
IC5: 7815TV; TO220V
IC6: VXO7805-1000; 78XX-DC-DC
IC10: LT4320DIL08; DIL08
IC15: LD33V; TO220V
IC17: 7818TV; TO220V
KK1: D01S
L1, L2, L4: MPZ2012S601AT000; C0805K
R17: 2k2 5% 1/8W; C0805K
R18, R25, R26: 1k 1% 1/8W; C0805K
T15, T16, T17, T18: IRFR7546TRPBF; DPACK

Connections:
+3.3V: C23.1, C24.1, L2.2; also elsewhere on the board
+3.3V_A: IC1.5 (OUT); also elsewhere on the board
+3.3V_A2: IC9.5 (OUT); also elsewhere on the board
+5V_INT_D: C38.1, IC15.3 (VI), L1.2; also elsewhere on the board
+12V: L4.2; also elsewhere on the board
+18V: C43.1, D9.A, IC17.3 (VO), R18.1; also elsewhere on the board
+27V: C1.+, C2.+, C12.2, C19.2, C21.1, C33.+, C42.1, C44.+, C53.1, D4.C, D9.C, IC4.1 (VI), IC5.1 (VI), IC6.1 (VI), IC10.6 (OUTP), IC17.1 (VI), T15.3 (D), T16.3 (D); also elsewhere on the board
AGND: C21.2, C28.2, C32.1, C35.1, C42.2, C43.2, IC1.2 (GND), IC5.2 (GND), IC9.2 (GND), IC17.2 (GND), R17.2, R26.2; also elsewhere on the board
unnamed: C20.2, IC6.3 (VO), L1.1
unnamed: AC2.1, AC2.2, IC10.1 (IN2), T15.2 (S), T18.3 (D)
unnamed: C16.2, IC4.3 (VO), L4.1
unnamed: R18.2, R25.1
unnamed: R25.2, R26.1
unnamed: C39.2, IC15.2 (VO), L2.1
unnamed: IC10.2 (TG2), T15.1 (G)
unnamed: IC10.3 (BG2), T17.1 (G)
unnamed: IC10.7 (TG1), T16.1 (G)
unnamed: IC10.4 (BG1), T18.1 (G)
unnamed: AC1.1, AC1.2, IC10.8 (IN1), T16.2 (S), T17.3 (D)
P_VSS: C1.-, C2.-, C53.2, IC10.5 (OUTN), T17.2 (S), T18.2 (S)
VSS: C12.1, C16.1, C19.1, C20.1, C23.2, C24.2, C33.-, C38.2, C39.1, C44.-, IC4.2 (GND), IC6.2 (GND), IC15.1 (GND); also elsewhere on the board

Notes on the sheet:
2x 10.000µF 50V
Voltage Sources
18V Trafo
6mA Pulldown

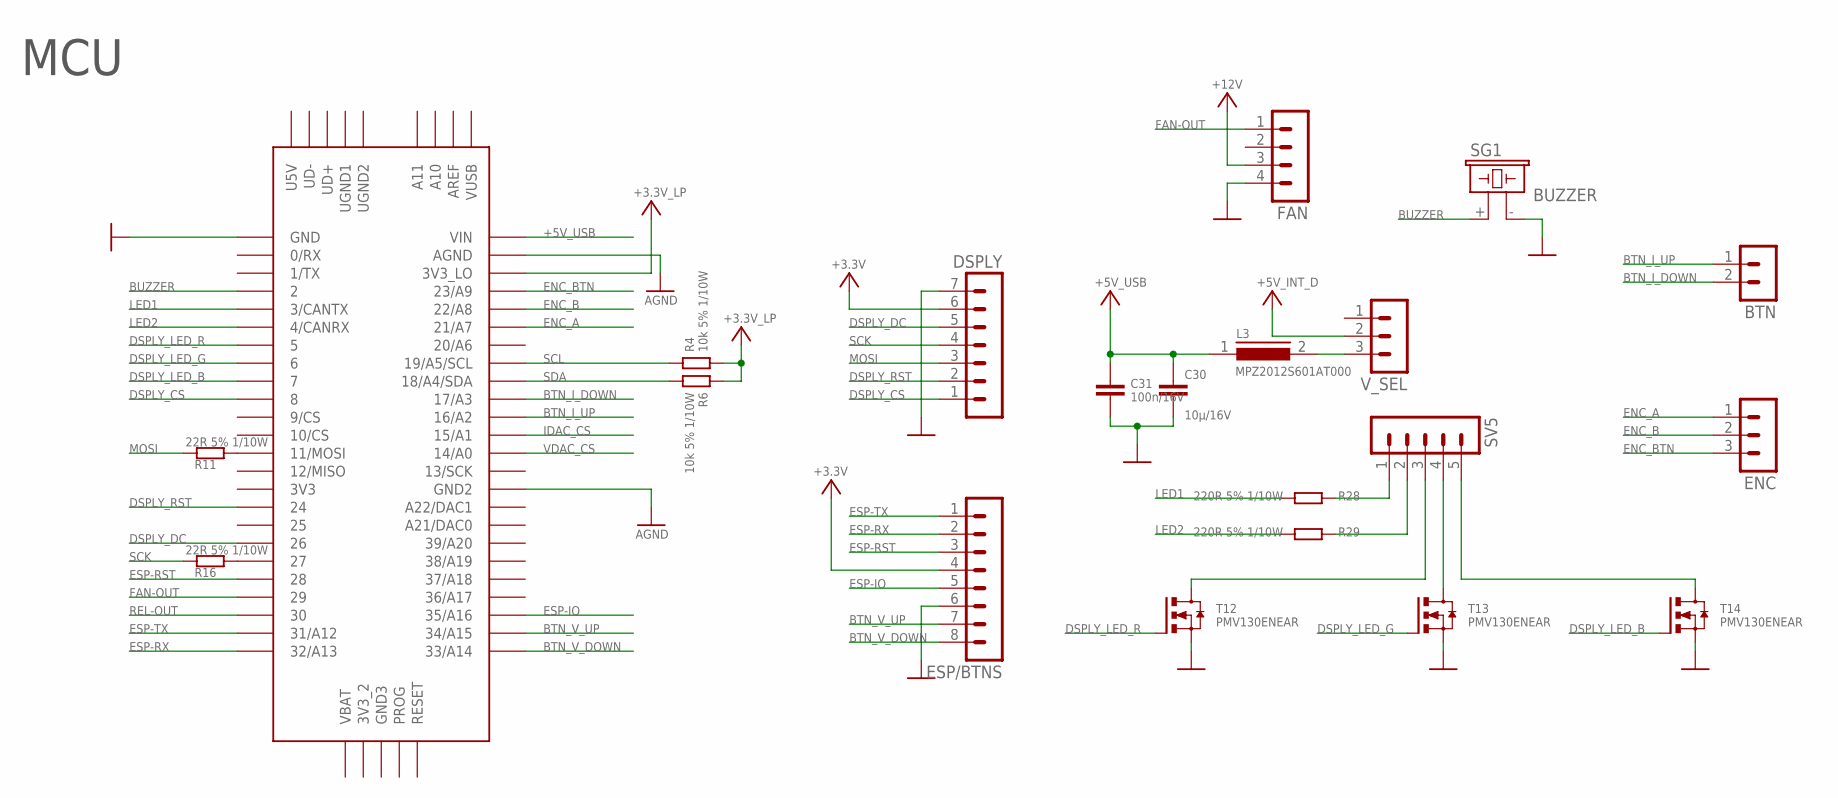
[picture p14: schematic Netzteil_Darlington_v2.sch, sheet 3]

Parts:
BTN: JST-PH-2.0-2P
C30: 10µ/16V; 1206
C31: 100n/16V; 0805
DSPLY: JST-PH-2.0-7P
ENC: JST-PH-2.0-3P
ESP/BTNS: JST-PH-2.0-8P
FAN: JST-PH-2.0-4P
L3: MPZ2012S601AT000; C0805K
R4, R6: 10k 5% 1/10W; C0805K
R11, R16: 22R 5% 1/10W; C0805K
R28, R29: 220R 5% 1/10W; C0805K
SG1: BUZZER; 254-EMB73-RO
SV5: JST-PH-2.0-5P
T12, T13, T14: PMV130ENEAR; SOT23
U$33: TEENSY_3.5/3.6
V_SEL: MA03-1

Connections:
+3.3V: DSPLY.6, ESP/BTNS.4; also elsewhere on the board
+3.3V_LP: R4.2, R6.1, U$33.3V3_LO
+5V_INT_D: V_SEL.2; also elsewhere on the board
+5V_USB: C30.1, C31.1, L3.1, U$33.VIN
+12V: FAN.3; also elsewhere on the board
AGND: U$33.AGND, U$33.GND2; also elsewhere on the board
BTN1: BTN.2, U$33.17/A3
BTN2: BTN.1, U$33.16/A2
BTN3: ESP/BTNS.8, U$33.33/A14
BTN4: ESP/BTNS.7, U$33.34/A15
BUZZER: SG1.+ (1), U$33.2
DSPLY_CS: DSPLY.1, U$33.8
DSPLY_DC: DSPLY.5, U$33.26
DSPLY_LED_B: T14.1 (G), U$33.7
DSPLY_LED_G: T13.1 (G), U$33.6
DSPLY_LED_R: T12.1 (G), U$33.5
DSPLY_RST: DSPLY.2, U$33.24
ENC_A: ENC.1, U$33.21/A7
ENC_B: ENC.2, U$33.22/A8
ENC_BTN: ENC.3, U$33.23/A9
ESP-IO: ESP/BTNS.5, U$33.35/A16
ESP-RST: ESP/BTNS.3, U$33.28
ESP-RX: ESP/BTNS.2, U$33.32/A13
ESP-TX: ESP/BTNS.1, U$33.31/A12
FAN-OUT: FAN.1, U$33.29
IDAC_CS: U$33.15/A1; also elsewhere on the board
LED1: R28.1, U$33.3/CANTX
LED2: R29.1, U$33.4/CANRX
MOSI: DSPLY.3, R11.1; also elsewhere on the board
unnamed 49: SV5.3, T12.3 (D); also elsewhere on the board
unnamed: R16.2, U$33.27
unnamed: R11.2, U$33.11/MOSI
unnamed 60: R28.2, SV5.1; also elsewhere on the board
unnamed 63: R29.2, SV5.2; also elsewhere on the board
unnamed: L3.2, V_SEL.3
unnamed 80: SV5.4, T13.3 (D); also elsewhere on the board
unnamed 82: SV5.5, T14.3 (D); also elsewhere on the board
REL-OUT: U$33.30; also elsewhere on the board
SCK: DSPLY.4, R16.1; also elsewhere on the board
SCL: R4.1, U$33.19/A5/SCL; also elsewhere on the board
SDA: R6.2, U$33.18/A4/SDA; also elsewhere on the board
VDAC_CS: U$33.14/A0; also elsewhere on the board
VSS: C30.2, C31.2, DSPLY.7, ESP/BTNS.6, FAN.4, SG1.- (2), T12.2 (S), T13.2 (S), T14.2 (S), U$33.GND; also elsewhere on the board

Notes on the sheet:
MCU

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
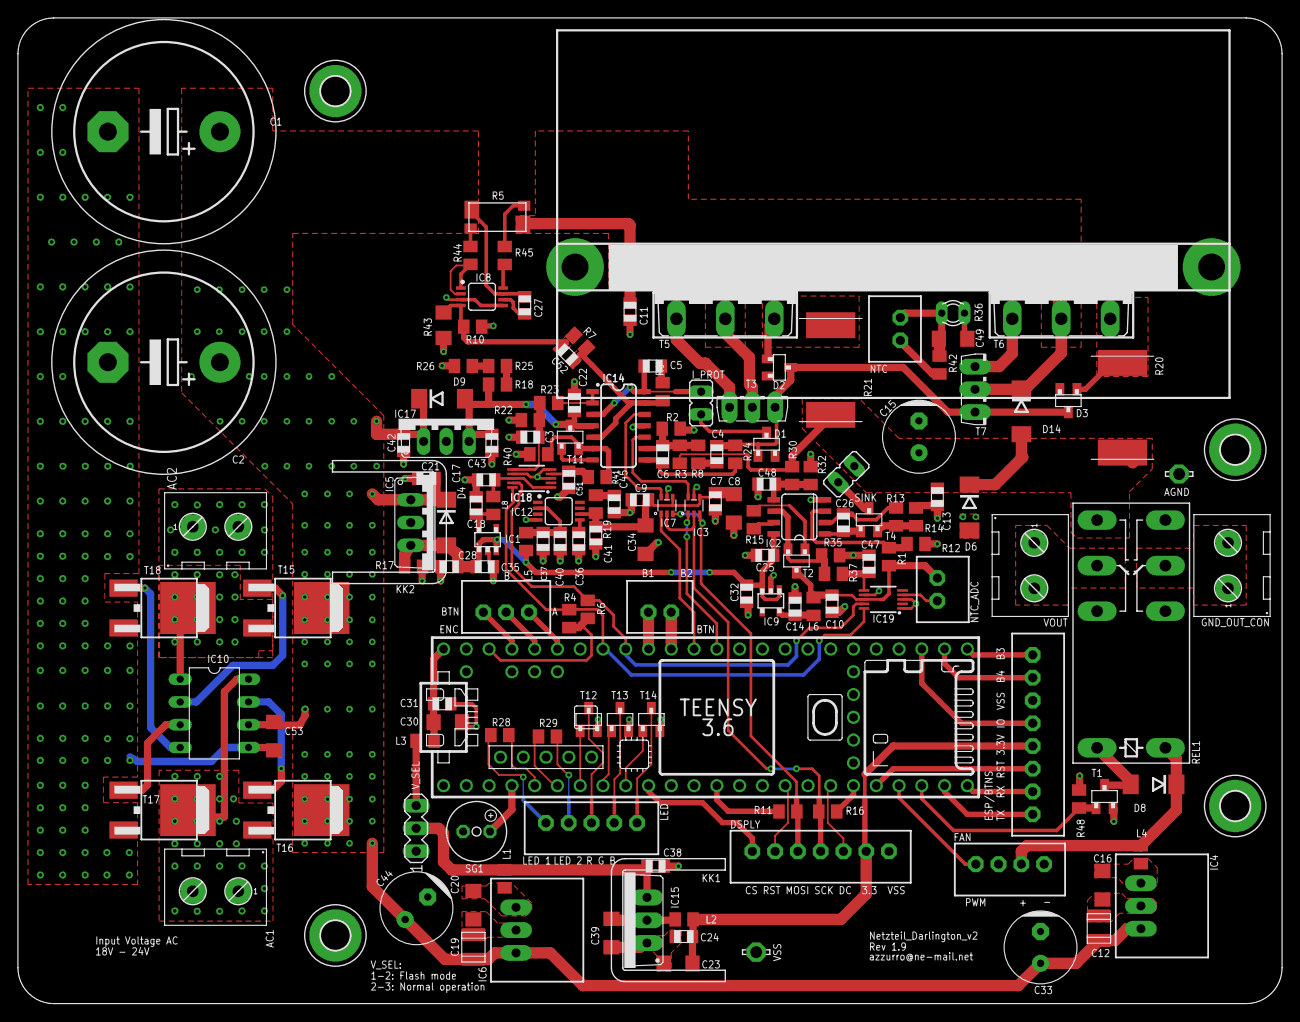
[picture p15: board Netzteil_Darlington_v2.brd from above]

Board: 2 copper layers, 141.0 x 109.9 mm, 163 parts (0 on the bottom side), 109 nets.

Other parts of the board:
KK2: D01S
LED: JST-PH-2.0-5P
NTC: JST-PH-2.0-2P
NTC_ADC: JST-PH-2.0-2P
R15: 1k5 5% 1/8W; C0805K

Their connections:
3.3V_TH: NTC.2; also elsewhere on the board
unnamed 49: LED.3; also elsewhere on the board
unnamed 60: LED.1; also elsewhere on the board
unnamed 63: LED.2; also elsewhere on the board
unnamed 80: LED.4; also elsewhere on the board
unnamed 82: LED.5; also elsewhere on the board
TH0: NTC.1; also elsewhere on the board
TH0_ADC: NTC_ADC.1; also elsewhere on the board

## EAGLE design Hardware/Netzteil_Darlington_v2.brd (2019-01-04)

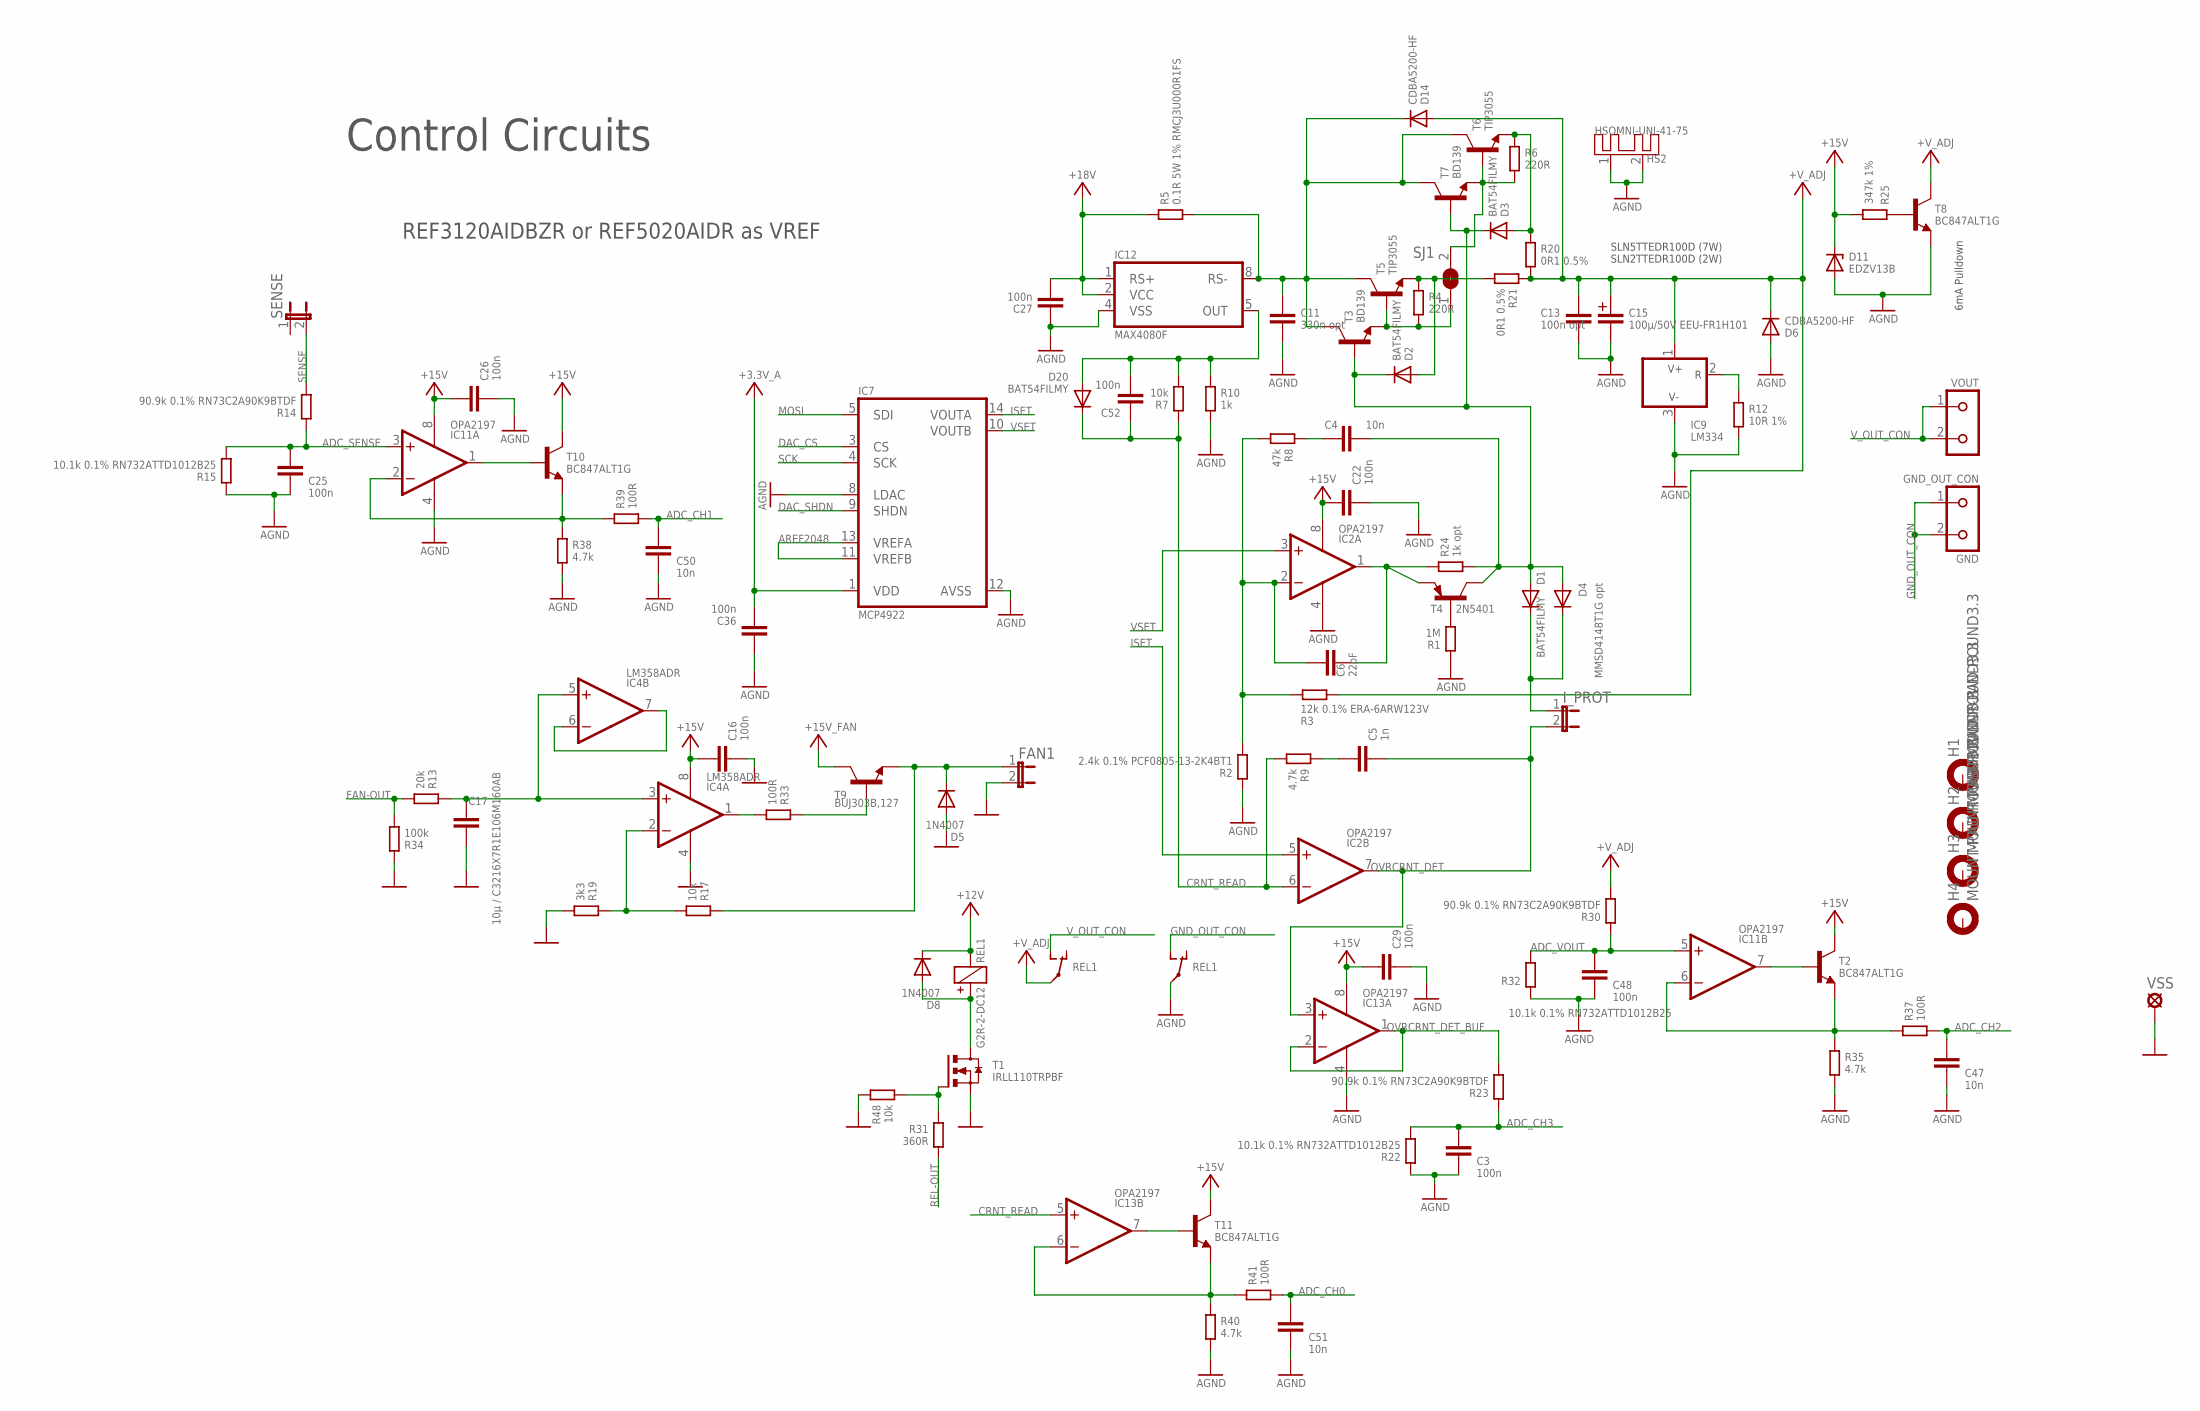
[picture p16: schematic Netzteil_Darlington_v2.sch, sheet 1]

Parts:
C3, C16, C22, C25, C26, C27, C29, C36, C48, C52: 100n; 0805
C4, C47, C50, C51: 10n; 0805
C5: 1n; 0805
C6: 22pF; 0805
C11: 330n opt; 0805
C13: 100n opt; 0805
C15: 100µ/50V EEU-FR1H101; C+/3.5/8
C17: 10µ / C3216X7R1E106M160AB; 1206
D1, D2, D3, D20: BAT54FILMY; SOT23
D4: MMSD4148T1G opt; SOD-123
D5, D8: 1N4007; DO214AA
D6, D14: CDBA5200-HF; DO214AC-2
D11: EDZV13B; SOD-523
FAN1: JP1E; JP1
GND_OUT_CON: GND; KL2-691311500002
H1, H2, H3, H4: MOUNT-PAD-ROUND3.3; 3,3-PAD
HS2: HSOMNI-UNI-41-75; OMNI-UNI-41-75
IC2, IC11, IC13: OPA2197; SOP8
IC4: LM358ADR; SOP8
IC7: MCP4922; TSSOP14
IC9: LM334; TO92-G
IC12: MAX4080F; SOP8
I_PROT: JP1E; JP1
R1: 1M; C0603K
R2: 2.4k 0.1% PCF0805-13-2K4BT1; C0805K
R3: 12k 0.1% ERA-6ARW123V; C0805K
R4, R6: 220R; C0805K
R5: 0.1R 5W 1% RMCJ3U000R1FS; RMC-J3
R7, R17, R48: 10k; C0805K
R8: 47k; C0805K
R9, R35, R38, R40: 4.7k; C0805K
R10: 1k; C0805K
R12: 10R 1%; C0805K
R13: 20k; C0805K
R14, R23, R30: 90.9k 0.1% RN73C2A90K9BTDF; C0805K
R15, R22, R32: 10.1k 0.1% RN732ATTD1012B25; C0805K
R19: 3k3; C0805K
R20, R21: 0R1 0.5%; SLN2
R24: 1k opt; C0805K
R25: 347k 1%; C0805K
R31: 360R; C0805K
R33, R37, R39, R41: 100R; C0805K
R34: 100k; C0805K
REL1: G2R-2-DC12; REL-G2R2
SENSE: JP1E; JP1
SJ1: SJ
T1: IRLL110TRPBF; SOT223-4
T2, T8, T10, T11: BC847ALT1G; SOT23-BEC
T3, T7: BD139; TO126
T4: 2N5401; TO92-G
T5, T6: TIP3055; TOP3AV
T9: BUJ303B,127; TO220V
VOUT: KL2691311500002; KL2-691311500002
VSS: LSP13

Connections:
+3.3V_A: C36.2, IC7.1 (VDD); also elsewhere on the board
+12V: D8.C, REL1.-; also elsewhere on the board
+15V: C16.1, C22.1, C26.1, C29.1, D11.C, IC2.8 (V+), IC4.8 (V+), IC11.8 (V+), IC13.8 (V+), R25.2, T2.C, T10.C, T11.C; also elsewhere on the board
+15V_FAN: T9.2 (C); also elsewhere on the board
+18V: C27.2, IC12.1 (RS+), IC12.2 (VCC), R5.1; also elsewhere on the board
+V_ADJ: C13.1, C15.+, D6.C, D14.A, IC9.1 (V+), R3.1, R20.2, R21.1, R30.2, REL1.P1, T8.C
ADC_CH0: C51.1, R41.2; also elsewhere on the board
ADC_CH1: C50.1, R39.2; also elsewhere on the board
ADC_CH2: C47.1, R37.2; also elsewhere on the board
ADC_CH3: C3.1, R22.2, R23.1; also elsewhere on the board
ADC_SENSE: C25.1, IC11.3 (+IN), R14.1, R15.2
ADC_VOUT: C48.1, IC11.5 (+IN), R30.1, R32.2
AGND: C3.2, C11.2, C13.2, C15.-, C22.2, C25.2, C26.2, C27.1, C29.2, C36.1, C47.2, C48.2, C50.2, C51.2, D6.A, D11.A, HS2.1, HS2.2, IC2.4 (V-), IC7.8 (LDAC), IC7.12 (AVSS), IC9.3 (V-), IC11.4 (V-), IC12.4 (VSS), IC13.4 (V-), R1.1, R2.1, R10.2, R12.2, R15.1, R22.1, R32.1, R35.2, R38.2, R40.2, REL1.P2, T8.E; also elsewhere on the board
AREF2048: IC7.11 (VREFB), IC7.13 (VREFA); also elsewhere on the board
CRNT_READ: C52.1, D20.3 (C), IC2.6 (-IN), IC13.5 (+IN), R7.1, R9.2
DAC_CS: IC7.3 (CS); also elsewhere on the board
DAC_SHDN: IC7.9 (SHDN); also elsewhere on the board
FAN-OUT: R13.2, R34.2; also elsewhere on the board
GND_OUT_CON: GND_OUT_CON.1, GND_OUT_CON.2, REL1.S2 (S)
ISET: IC2.5 (+IN), IC7.14 (VOUTA)
MOSI: IC7.5 (SDI); also elsewhere on the board
unnamed: C11.1, D14.C, IC12.8 (RS-), R5.2, T3.2 (C), T5.C, T6.C, T7.2 (C)
unnamed: D3.1 (A), R6.1, R20.1, T6.E
unnamed: R6.2, SJ1.2, T6.B, T7.1 (E)
unnamed: C6.1, IC2.2 (-IN), R2.2, R3.2, R8.2
unnamed: C52.2, D20.1 (A), IC12.5 (OUT), R7.2, R10.1
unnamed: D2.1 (A), R4.1, R21.2, T5.E
unnamed: D1.3 (C), D4.C, I_PROT.1
unnamed: R25.1, T8.B
unnamed: D8.A, REL1.+, T1.2 (D), T1.4 (D)
unnamed: R4.2, SJ1.1, T3.1 (E), T5.B
unnamed: IC9.2 (R), R12.1
unnamed: IC4.6 (-IN), IC4.7 (OUT)
unnamed: R1.2, T4.2 (B)
unnamed: C6.2, IC2.1 (OUT), R24.1, T4.1 (E)
unnamed: C4.2, D1.1 (A), D2.3 (C), D3.3 (C), D4.A, R24.2, T3.3 (B), T4.3 (C), T7.3 (B)
unnamed: C4.1, R8.1
unnamed: C5.1, R9.1
unnamed: C17.2, IC4.3 (+IN), IC4.5 (+IN), R13.1
unnamed: D5.C, FAN1.1, R17.1, T9.3 (E)
unnamed: IC4.2 (-IN), R17.2, R19.1
unnamed: R33.1, T9.1 (B)
unnamed: IC4.1 (OUT), R33.2
unnamed: R31.1, R48.2, T1.1 (G)
unnamed: IC11.7 (OUT), T2.B
unnamed: IC11.6 (-IN), R35.1, R37.1, T2.E
unnamed: IC11.1 (OUT), T10.B
unnamed: IC11.2 (-IN), R38.1, R39.1, T10.E
unnamed: IC13.7 (OUT), T11.B
unnamed: IC13.6 (-IN), R40.1, R41.1, T11.E
OVRCRNT_DET: C5.2, IC2.7 (OUT), IC13.3 (+IN), I_PROT.2
OVRCRNT_DET_BUF: IC13.1 (OUT), IC13.2 (-IN), R23.2
REL-OUT: R31.2; also elsewhere on the board
SCK: IC7.4 (SCK); also elsewhere on the board
SENSE: R14.2, SENSE.2
VSET: IC2.3 (+IN), IC7.10 (VOUTB)
VSS: C16.2, C17.1, D5.A, FAN1.2, IC4.4 (V-), R19.2, R34.1, R48.1, T1.3 (S), VSS.MP; also elsewhere on the board
V_OUT_CON: REL1.S1 (S), VOUT.1, VOUT.2

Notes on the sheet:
Control Circuits
6mA Pulldown
SLN5TTEDR100D (7W) SLN2TTEDR100D (2W)
REF3120AIDBZR or REF5020AIDR as VREF

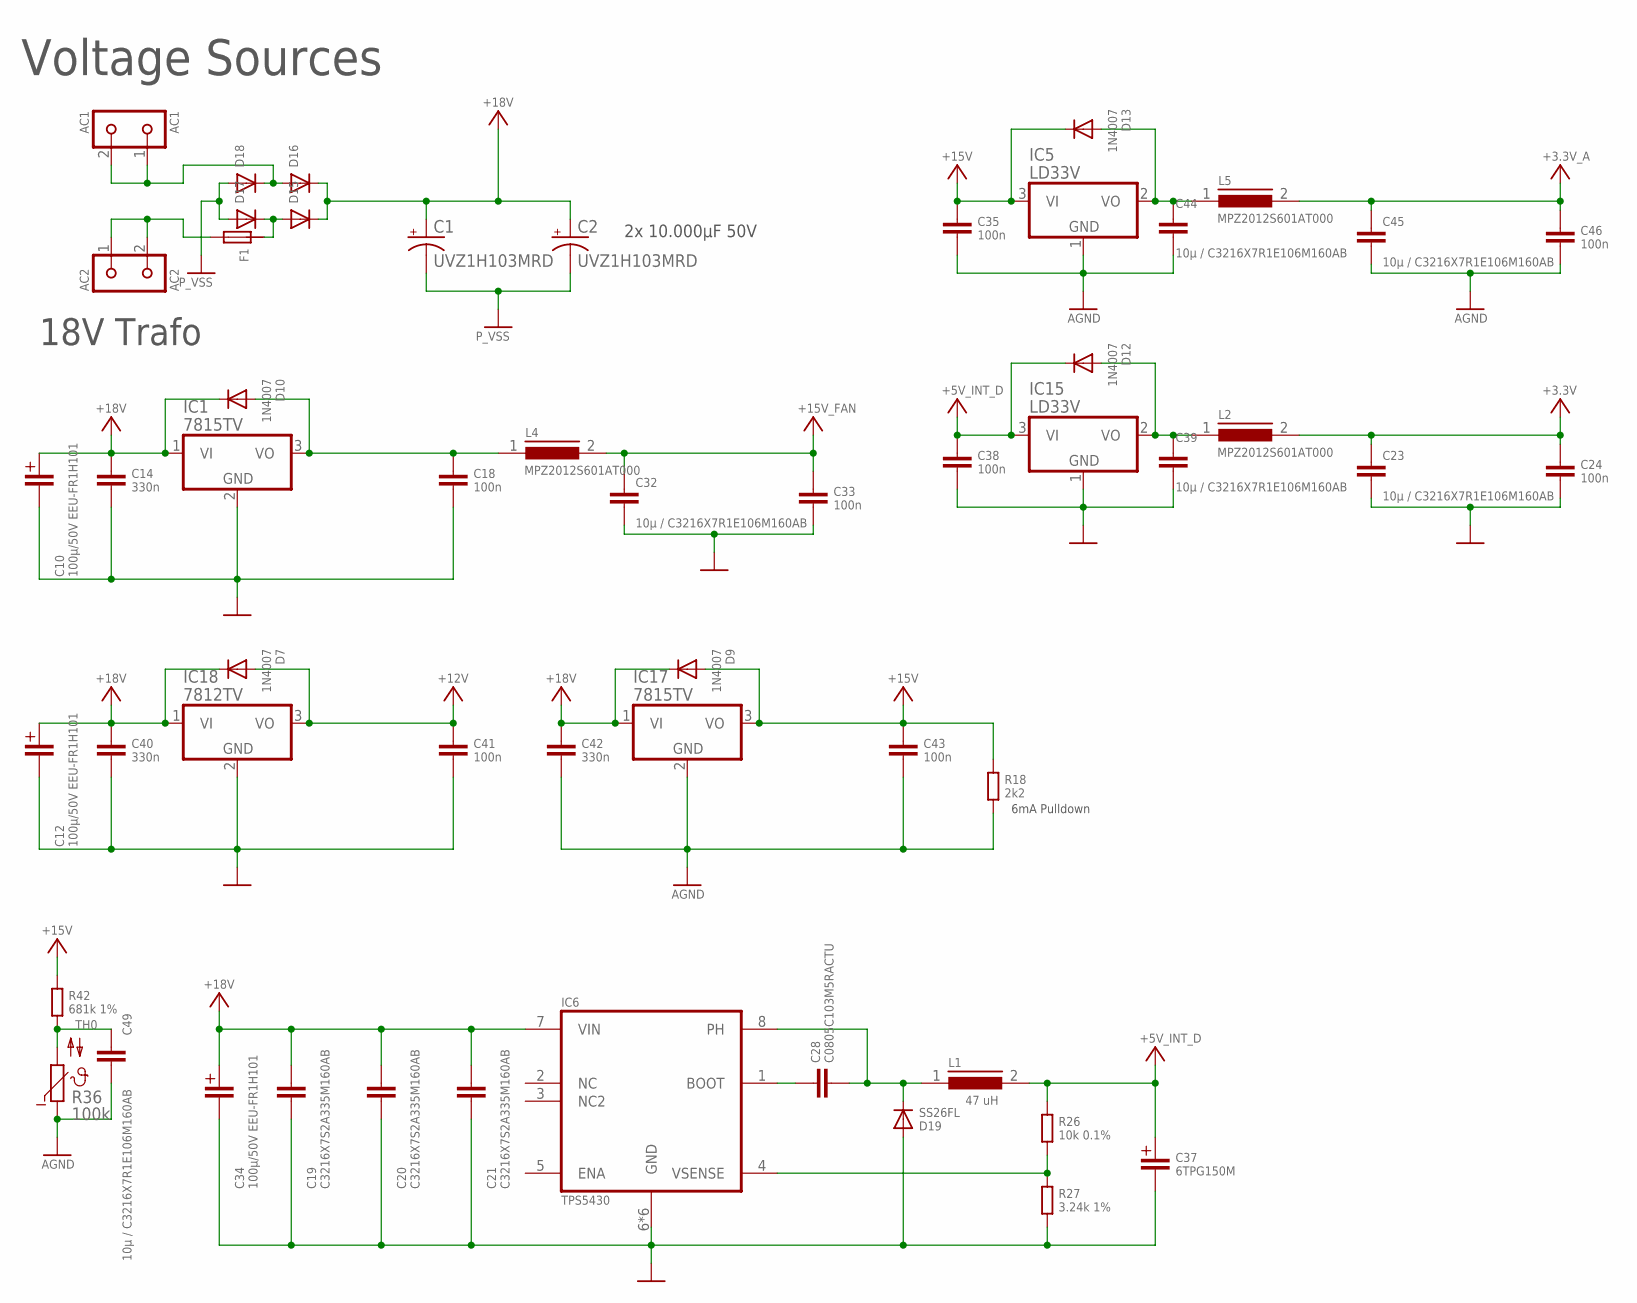
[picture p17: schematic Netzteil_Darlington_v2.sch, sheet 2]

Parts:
AC1: AC1; KL2-691311500002
AC2: AC2; KL2-691311500002
C1, C2: UVZ1H103MRD; EB22,5D
C10, C12, C34: 100µ/50V EEU-FR1H101; C+/3.5/8
C14, C40, C42: 330n; 0805
C18, C24, C33, C35, C38, C41, C43, C46: 100n; 0805
C19, C20, C21: C3216X7S2A335M160AB; 1206
C23, C32, C39, C44, C45, C49: 10µ / C3216X7R1E106M160AB; 1206
C28: C0805C103M5RACTU; 0805
C37: 6TPG150M; CT1210
D7, D9, D10, D12, D13: 1N4007; DO214AA
D15, D16, D17, D18: DTO263-PWR; TO-263AB-PWR
D19: SS26FL; SOD-123
F1: F5X20
IC1, IC17: 7815TV; TO220V
IC5, IC15: LD33V; TO220V
IC6: TPS5430; SOIC8POWERPAD
IC18: 7812TV; TO220V
L1: 47 uH; WE-PD
L2, L4, L5: MPZ2012S601AT000; C0805K
R18: 2k2; C0805K
R26: 10k 0.1%; C0805K
R27: 3.24k 1%; C0805K
R36: 100k; P640
R42: 681k 1%; C0603K

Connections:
+3.3V: C23.1, C24.1, L2.2; also elsewhere on the board
+3.3V_A: C45.1, C46.1, L5.2; also elsewhere on the board
+5V_INT_D: C37.+, C38.1, D12.C, IC15.3 (VI), L1.2, R26.1; also elsewhere on the board
+12V: C41.1, D7.A, IC18.3 (VO); also elsewhere on the board
+15V: C35.1, C43.1, D9.A, D13.C, IC5.3 (VI), IC17.3 (VO), R18.1, R42.1; also elsewhere on the board
+15V_FAN: C32.1, C33.1, L4.2; also elsewhere on the board
+18V: C1.+, C2.+, C10.+, C12.+, C14.1, C19.1, C20.1, C21.1, C34.+, C40.1, C42.1, D7.C, D9.C, D10.C, D15.2 (C), D15.2_PWR1 (C), D15.2_PWR2 (C), D15.2_PWR3 (C), D15.2_PWR4 (C), D15.2_PWR5 (C), D15.2_PWR6 (C), D15.2_PWR7 (C), D15.2_PWR8 (C), D15.2_PWR9 (C), D15.2_PWR10 (C), D15.2_PWR11 (C), D15.2_PWR12 (C), D16.2 (C), D16.2_PWR1 (C), D16.2_PWR2 (C), D16.2_PWR3 (C), D16.2_PWR4 (C), D16.2_PWR5 (C), D16.2_PWR6 (C), D16.2_PWR7 (C), D16.2_PWR8 (C), D16.2_PWR9 (C), D16.2_PWR10 (C), D16.2_PWR11 (C), D16.2_PWR12 (C), IC1.1 (VI), IC6.7 (VIN), IC17.1 (VI), IC18.1 (VI); also elsewhere on the board
AGND: C35.2, C42.2, C43.2, C44.1, C45.2, C46.2, C49.1, IC5.1 (GND), IC17.2 (GND), R18.2, R36.1; also elsewhere on the board
unnamed: C28.1, IC6.1 (BOOT)
unnamed: AC2.1, AC2.2, F1.3 (2), F1.4 (2)
unnamed: C28.2, D19.- (C), IC6.8 (PH), L1.1
unnamed: AC1.1, AC1.2, D16.1 (A), D16.3 (A), D18.2 (C), D18.2_PWR1 (C), D18.2_PWR2 (C), D18.2_PWR3 (C), D18.2_PWR4 (C), D18.2_PWR5 (C), D18.2_PWR6 (C), D18.2_PWR7 (C), D18.2_PWR8 (C), D18.2_PWR9 (C), D18.2_PWR10 (C), D18.2_PWR11 (C), D18.2_PWR12 (C)
unnamed: IC6.4 (VSENSE), R26.2, R27.1
unnamed: D15.1 (A), D15.3 (A), D17.2 (C), D17.2_PWR1 (C), D17.2_PWR2 (C), D17.2_PWR3 (C), D17.2_PWR4 (C), D17.2_PWR5 (C), D17.2_PWR6 (C), D17.2_PWR7 (C), D17.2_PWR8 (C), D17.2_PWR9 (C), D17.2_PWR10 (C), D17.2_PWR11 (C), D17.2_PWR12 (C), F1.1, F1.2 (1)
unnamed: C39.2, D12.A, IC15.2 (VO), L2.1
unnamed: C18.1, D10.A, IC1.3 (VO), L4.1
unnamed: C44.2, D13.A, IC5.2 (VO), L5.1
P_VSS: C1.-, C2.-, D17.1 (A), D17.3 (A), D18.1 (A), D18.3 (A)
TH0: C49.2, R36.2, R42.2; also elsewhere on the board
VSS: C10.-, C12.-, C14.2, C18.2, C19.2, C20.2, C21.2, C23.2, C24.2, C32.2, C33.2, C34.-, C37.-, C38.2, C39.1, C40.2, C41.2, D19.+ (A), IC1.2 (GND), IC6.6 (GND), IC6.POWERPAD (GND), IC6.PP1 (GND), IC6.PP2 (GND), IC6.PP3 (GND), IC6.PP4 (GND), IC15.1 (GND), IC18.2 (GND), R27.2; also elsewhere on the board

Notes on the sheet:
2x 10.000µF 50V
Voltage Sources
18V Trafo
6mA Pulldown

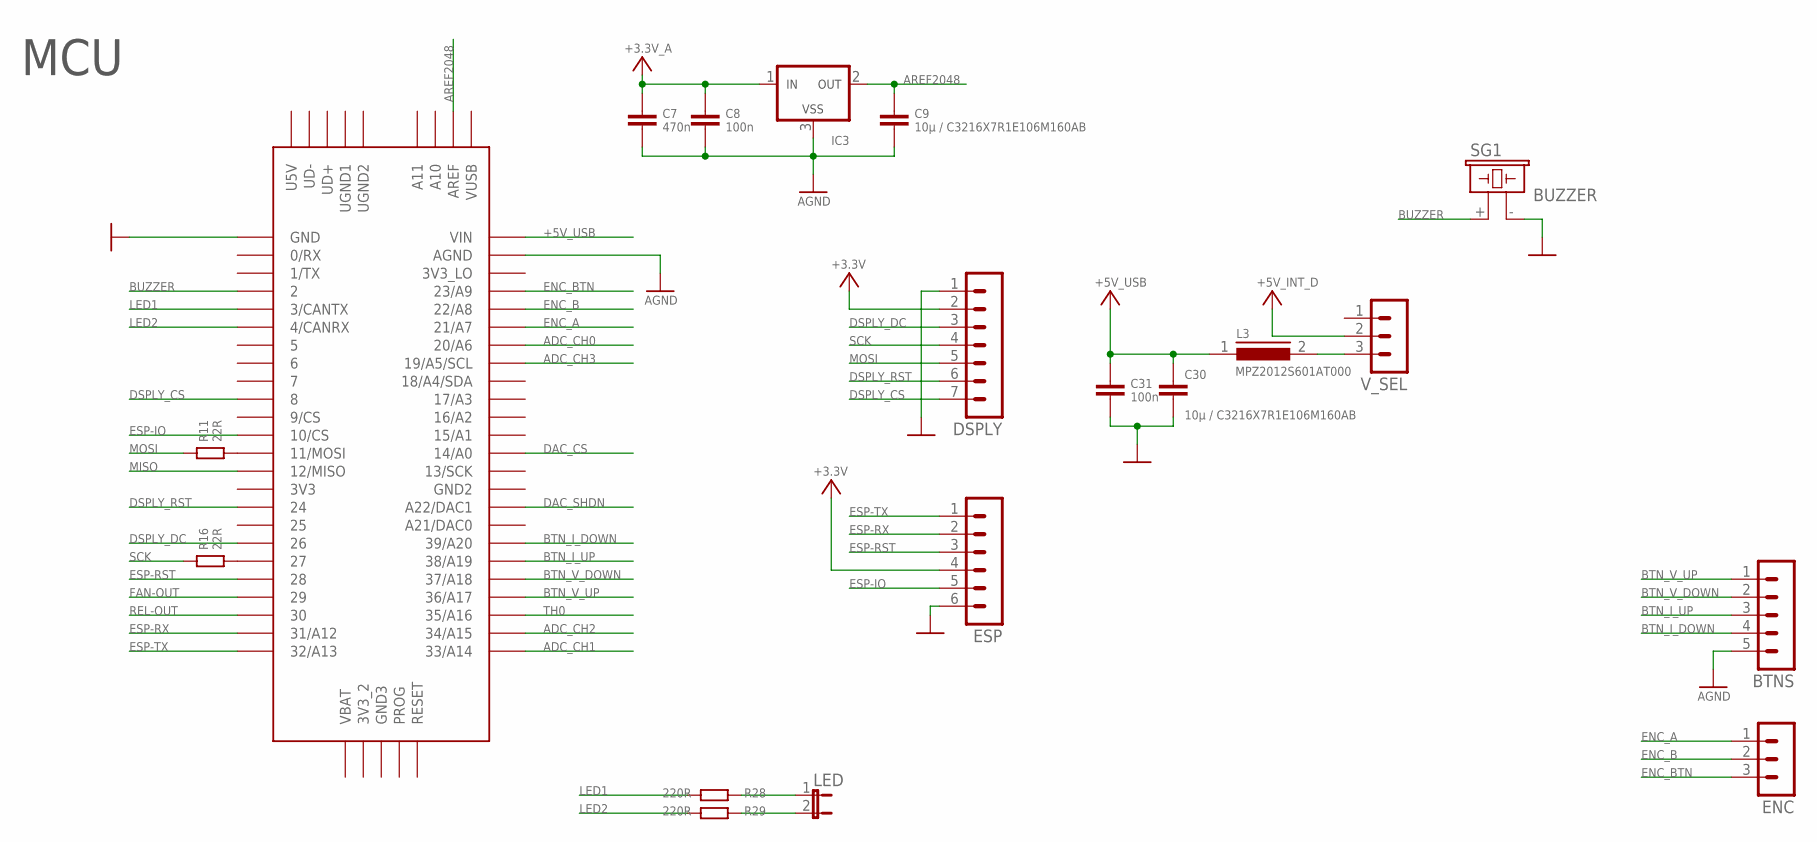
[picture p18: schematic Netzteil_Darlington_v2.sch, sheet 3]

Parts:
BTNS: MA05-1
C7: 470n; 0805
C8, C31: 100n; 0805
C9, C30: 10µ / C3216X7R1E106M160AB; 1206
DSPLY: MA07-1
ENC: MA03-1
ESP: MA06-1
IC3: REF3120; SOT23
L3: MPZ2012S601AT000; C0805K
LED: JP1E; JP1
R11, R16: 22R; C0805K
R28, R29: 220R; C0805K
SG1: BUZZER; 254-EMB73-RO
U$33: TEENSY_3.5/3.6
V_SEL: MA03-1

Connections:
+3.3V: DSPLY.2, ESP.4; also elsewhere on the board
+3.3V_A: C7.1, C8.1, IC3.1 (IN); also elsewhere on the board
+5V_INT_D: V_SEL.2; also elsewhere on the board
+5V_USB: C30.1, C31.1, L3.1, U$33.VIN
ADC_CH0: U$33.20/A6; also elsewhere on the board
ADC_CH1: U$33.33/A14; also elsewhere on the board
ADC_CH2: U$33.34/A15; also elsewhere on the board
ADC_CH3: U$33.19/A5/SCL; also elsewhere on the board
AGND: BTNS.5, C7.2, C8.2, C9.2, IC3.3 (VSS), U$33.AGND; also elsewhere on the board
AREF2048: C9.1, IC3.2 (OUT), U$33.AREF; also elsewhere on the board
BTN_I_DOWN: BTNS.4, U$33.39/A20
BTN_I_UP: BTNS.3, U$33.38/A19
BTN_V_DOWN: BTNS.2, U$33.37/A18
BTN_V_UP: BTNS.1, U$33.36/A17
BUZZER: SG1.+ (1), U$33.2
DAC_CS: U$33.14/A0; also elsewhere on the board
DAC_SHDN: U$33.A22/DAC1; also elsewhere on the board
DSPLY_CS: DSPLY.7, U$33.8
DSPLY_DC: DSPLY.3, U$33.26
DSPLY_RST: DSPLY.6, U$33.24
ENC_A: ENC.1, U$33.21/A7
ENC_B: ENC.2, U$33.22/A8
ENC_BTN: ENC.3, U$33.23/A9
ESP-IO: ESP.5, U$33.10/CS
ESP-RST: ESP.3, U$33.28
ESP-RX: ESP.2, U$33.31/A12
ESP-TX: ESP.1, U$33.32/A13
FAN-OUT: U$33.29; also elsewhere on the board
LED1: R28.1, U$33.3/CANTX
LED2: R29.1, U$33.4/CANRX
MISO: U$33.12/MISO
MOSI: DSPLY.5, R11.1; also elsewhere on the board
unnamed: R16.2, U$33.27
unnamed: R11.2, U$33.11/MOSI
unnamed: LED.1, R28.2
unnamed: LED.2, R29.2
unnamed: L3.2, V_SEL.3
REL-OUT: U$33.30; also elsewhere on the board
SCK: DSPLY.4, R16.1; also elsewhere on the board
TH0: U$33.35/A16; also elsewhere on the board
VSS: C30.2, C31.2, DSPLY.1, ESP.6, SG1.- (2), U$33.GND; also elsewhere on the board

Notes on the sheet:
MCU

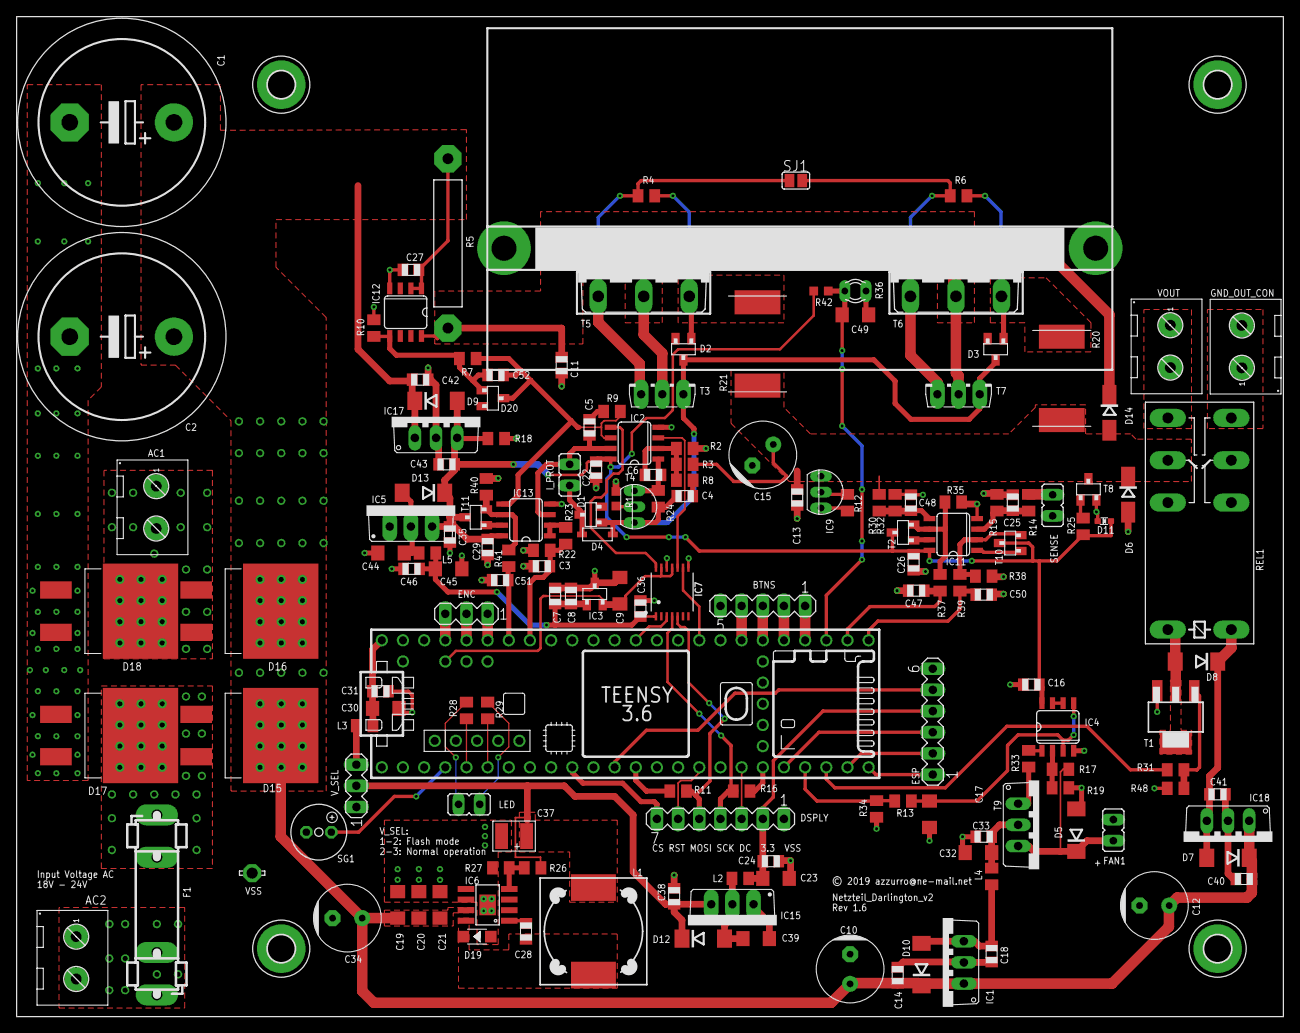
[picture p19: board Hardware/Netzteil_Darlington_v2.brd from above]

Board: 2 copper layers, 152.0 x 120.0 mm, 169 parts (0 on the bottom side), 94 nets.

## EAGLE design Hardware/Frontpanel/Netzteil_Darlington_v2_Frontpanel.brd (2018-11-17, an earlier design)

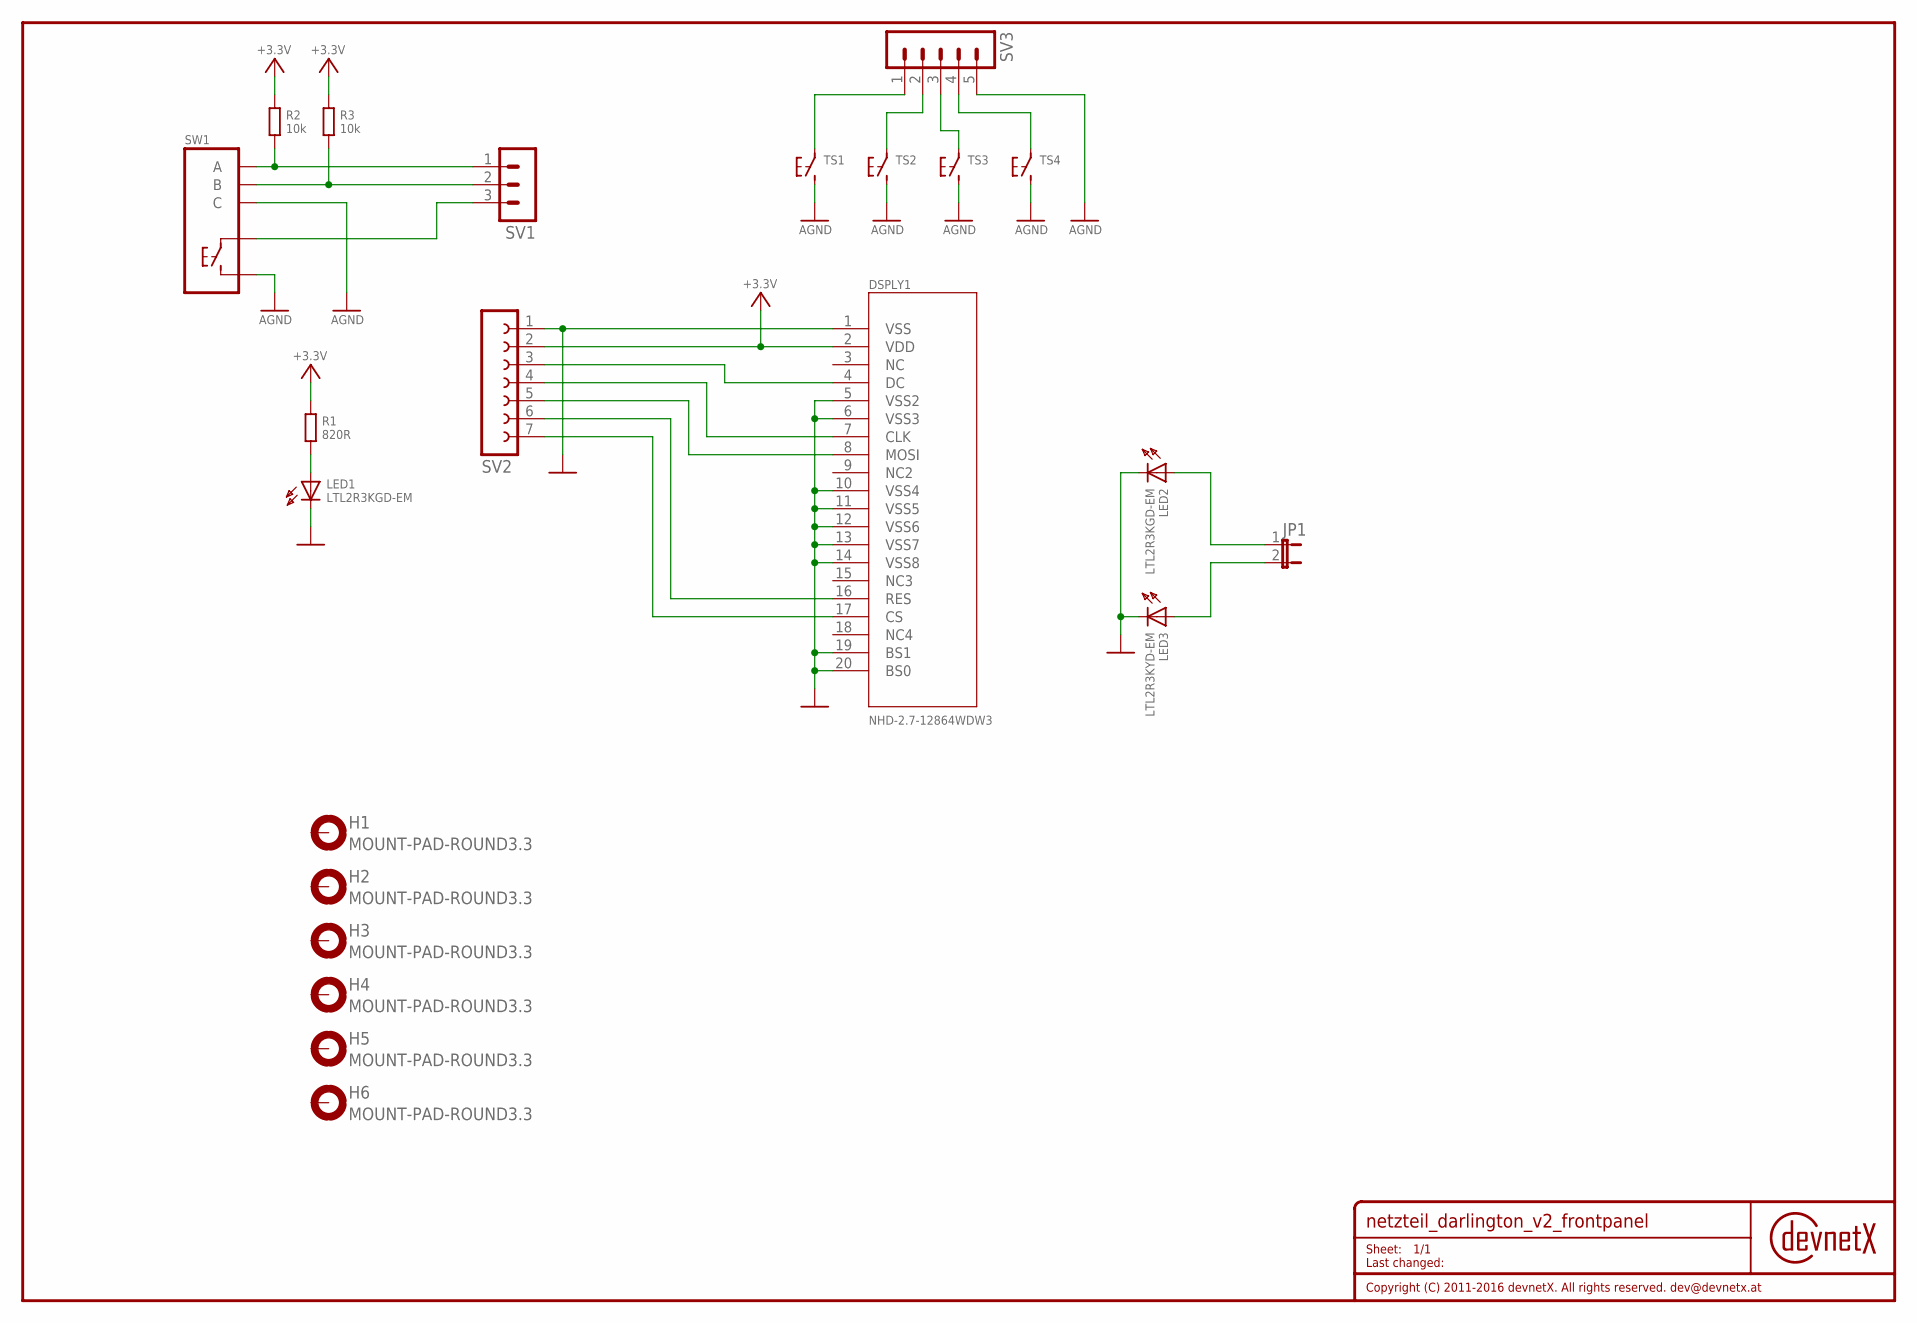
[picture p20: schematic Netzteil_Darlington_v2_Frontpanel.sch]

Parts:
DNX-NAME-1: DOC-R1.27; DRAWINGNAME-1.27
DSPLY1: NHD-2.7-12864WDW3
H1, H2, H3, H4, H5, H6: MOUNT-PAD-ROUND3.3; 3,3-PAD
JP1: JP1E; JP1
LED1, LED2: LTL2R3KGD-EM; LED5MM
LED3: LTL2R3KYD-EM; LED5MM
R1: 820R; C0805K
R2, R3: 10k; C0805K
SV1: MA03-1
SV2: FE07-1; FE07
SV3: MA05-1
SW1: EC12E-SW
TS1, TS2, TS3, TS4: TS1B3F-10XX; B3F-10XX

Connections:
+3.3V: DSPLY1.2 (VDD), R1.1, R2.1, R3.1, SV2.2
AGND: SV3.5, SW1.2, SW1.C, TS1.3 (2), TS2.3 (2), TS3.3 (2), TS4.3 (2)
unnamed: JP1.1, LED2.A
unnamed: JP1.2, LED3.A
unnamed: DSPLY1.4 (DC), SV2.3
unnamed: SV3.1, TS1.1
unnamed: R2.2, SV1.1, SW1.A
unnamed: DSPLY1.7 (CLK), SV2.4
unnamed: DSPLY1.8 (MOSI), SV2.5
unnamed: R3.2, SV1.2, SW1.B
unnamed: SV1.3, SW1.1
unnamed: SV3.2, TS2.1
unnamed: SV3.3, TS3.1
unnamed: SV3.4, TS4.1
unnamed: DSPLY1.16 (RES), SV2.6
unnamed: DSPLY1.17 (CS), SV2.7
unnamed: LED1.A, R1.2
VSS: DSPLY1.1 (VSS), DSPLY1.5 (VSS2), DSPLY1.6 (VSS3), DSPLY1.10 (VSS4), DSPLY1.11 (VSS5), DSPLY1.12 (VSS6), DSPLY1.13 (VSS7), DSPLY1.14 (VSS8), DSPLY1.19 (BS1), DSPLY1.20 (BS0), LED1.C, LED2.C, LED3.C, SV2.1

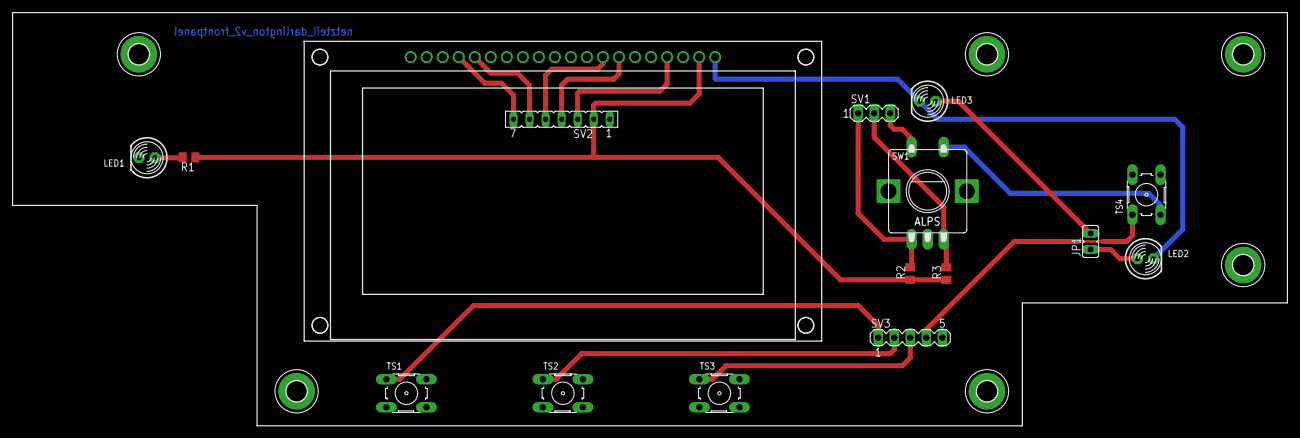
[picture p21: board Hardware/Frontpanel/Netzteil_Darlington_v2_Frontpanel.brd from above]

Board: 2 copper layers, 202.0 x 65.5 mm, 23 parts (0 on the bottom side), 18 nets.

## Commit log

2018-11-17 Add files via upload
    fix second, floating, unused ISET opamp (IC5B)
    [Netzteil_Darlington_v2.brd, Netzteil_Darlington_v2.sch]
2019-01-04 update to rev 1.6
    fix several bugs and issues
    [Netzteil_Darlington_v2.brd, Netzteil_Darlington_v2.sch]
2019-05-26 update to rev 1.8
    [Netzteil_Darlington_v2.brd, Netzteil_Darlington_v2.sch]
2019-06-11 update to latest version
    [Netzteil_Darlington_v2.brd, Netzteil_Darlington_v2.sch]
2019-07-11 Update to v1.9
    [Netzteil_Darlington_v2.brd, Netzteil_Darlington_v2.sch]
2019-07-12 repair designators, add gerber files
    [Netzteil_Darlington_v2.brd]
2019-07-21 add BOM
    [BOM.xlsx]
2019-07-21 add front panel
    [BOM_Frontpanel.xlsx, Netzteil_Darlington_v2_Frontpanel.brd, Netzteil_Darlington_v2_Frontpanel.sch]

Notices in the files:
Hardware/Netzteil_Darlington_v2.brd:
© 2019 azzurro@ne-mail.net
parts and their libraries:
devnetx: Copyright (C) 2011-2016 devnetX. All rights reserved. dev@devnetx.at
